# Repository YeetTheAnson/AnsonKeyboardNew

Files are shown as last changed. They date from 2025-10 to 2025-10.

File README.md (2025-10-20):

# Anson's Keyboard
This is a generic looking 80% TKL keyboard I made over the span of a month. In total, I've spent about 20-25 hours in total for PCB redesigns, writing the keyboard firmware and case redesigns.

## Features
- Individually backlit keys with software addressable RGB
- 0.91" OLED display
- USB and Bluetooth connectivity

### LED Control
The keyboard has three LED modes:
1. **Off Mode**: All LEDs are turned off
2. **RGB Mode**: LEDs display a rainbow effect
3. **Custom Color Mode**: All LEDs use a user-defined color

### LED Mode Controls
* **Toggle LED Mode**: `Ctrl + Alt + Pause/Break`
   * Cycles through Off → RGB → Custom Color
* **Adjust Brightness Up**: `Ctrl + Alt + Shift + Up Arrow`
* **Adjust Brightness Down**: `Ctrl + Alt + Shift + Down Arrow`

### Custom Color Configuration
1. **Enter Custom Color Mode**: `Ctrl + Alt + Page Up`
2. When in custom color mode:
   * The OLED will prompt for R, G, and B values sequentially
   * Use number keys (0-9) to enter a value between 0-255
   * Press `Backspace` to delete the last digit
   * Press `Enter` to confirm and move to the next color component
   * After setting all three RGB values, the keyboard returns to normal operation with your custom color

### Bluetooth Functionality
The keyboard can operate in either USB or Bluetooth mode:
* **Check Current Mode**: The OLED screen displays either "USB Mode" or "BT Mode"
* **Switch to Bluetooth Mode**: Hold the Pause/Break key during boot (pin IO36)
   * Note: After setup, the keyboard will remain in Bluetooth mode until changed

### OLED Display
The OLED display shows:
1. "AnsonKeyboard"
2. Connection mode (USB or Bluetooth)
3. Current WPM (words per minute) typing speed
4. Current LED mode

When in custom color configuration mode, the display shows prompts for entering RGB values.

### Performance Monitoring
The keyboard automatically calculates your typing speed (WPM) and displays it on the OLED screen. This is calculated based on:
* Number of keypresses
* Time elapsed since last keypress
* Standard conversion (5 characters = 1 word)

### Special Key Combinations
| Function | Key Combination |
|---|---|
| Toggle LED Mode | Ctrl + Alt + Pause/Break |
| Enter Custom Color Mode | Ctrl + Alt + Page Up |
| Increase LED Brightness | Ctrl + Alt + Shift + Up Arrow |
| Decrease LED Brightness | Ctrl + Alt + Shift + Down Arrow |
| Enter Bluetooth Mode | Hold Pause/Break during boot |

## Design Process
I started with a simple idea which was a flat minimalistic TKL keyboard (inspired by the Apple keyboard). The goal was to keep it clean and 
modern, and remove unnecessary designs. However, as I thought more about ergonomics, I quickly realized that a completely flat keyboard wouldn't be comfortable at all
to use during typing.

My initial PCB design had borders that were too thick, which also made the case borders too thick, it was quite bulky and uglier than what I wanted

I originally planned to use the Orpheus Pico as the microcontroller. However, due to the large footprint (making the case even bulkier) and the lack of wireless connectivity, I scrapped that idea
and moved on to a new design. At this point, I also decided to make a triangle wedge to set the keyboard at 6 degrees for a better typing experience.

I wanted an integrated USB C port directly on the PCB, but when I redesigned the case and PCB to fit it, I realized that it would be close to impossible for someone with my skill level to hand solder the USB C port and it
would have stuck up at an angle anyway (this stresses the cable)

For the final design, I came up a solution. Instead of mounting the USB C port directly onto the PCB, I would purchase a USB C breakout board instead and connect it via cables to the PCB. 

(This is when the routing hell begins as I reroute the entire thing at least 3 times)
The first time was my extremely inefficient matrix which was a 8x11 matrix. The traces were extremely messy and I've counted about 1.1k traces and 500 vias in total. (I'm so glad I don't have to see it again). I've then updated it to a 7x14 matrix which made routing much easier.
The second time was when I had to move all LEDs down by 2mm since they didn't align with the cutout in the switches.
Not even an hour after posting about my rerouting, someone from Slack recommmended that I wire my LEDs from top to bottom instead of side to side as to reduce via usage. This is the current version of the PCB and I'm quite happy with it

# Pictures
## Schematic
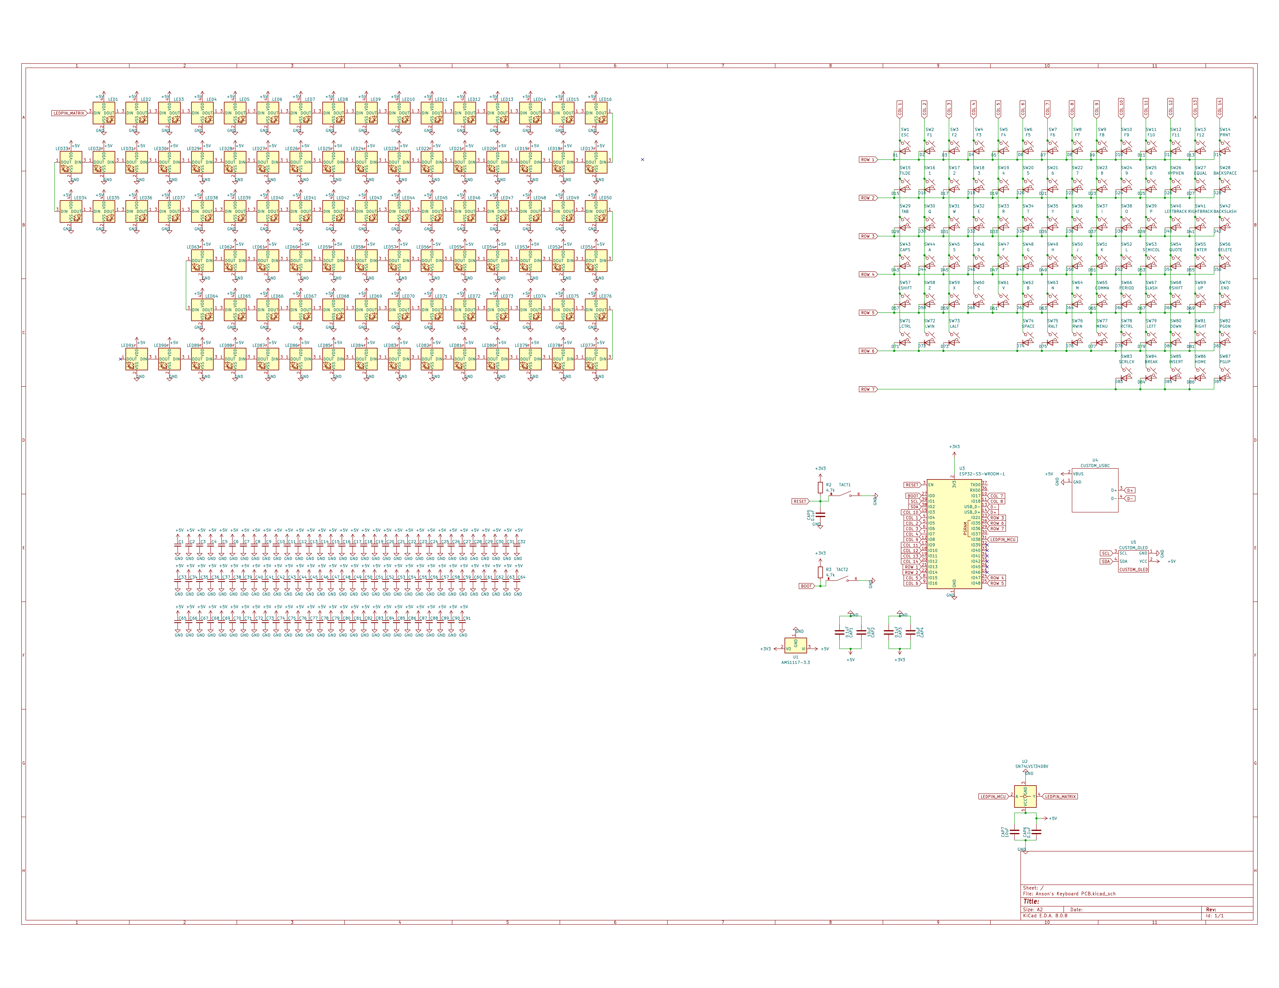
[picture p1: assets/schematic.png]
schematic


## PCB
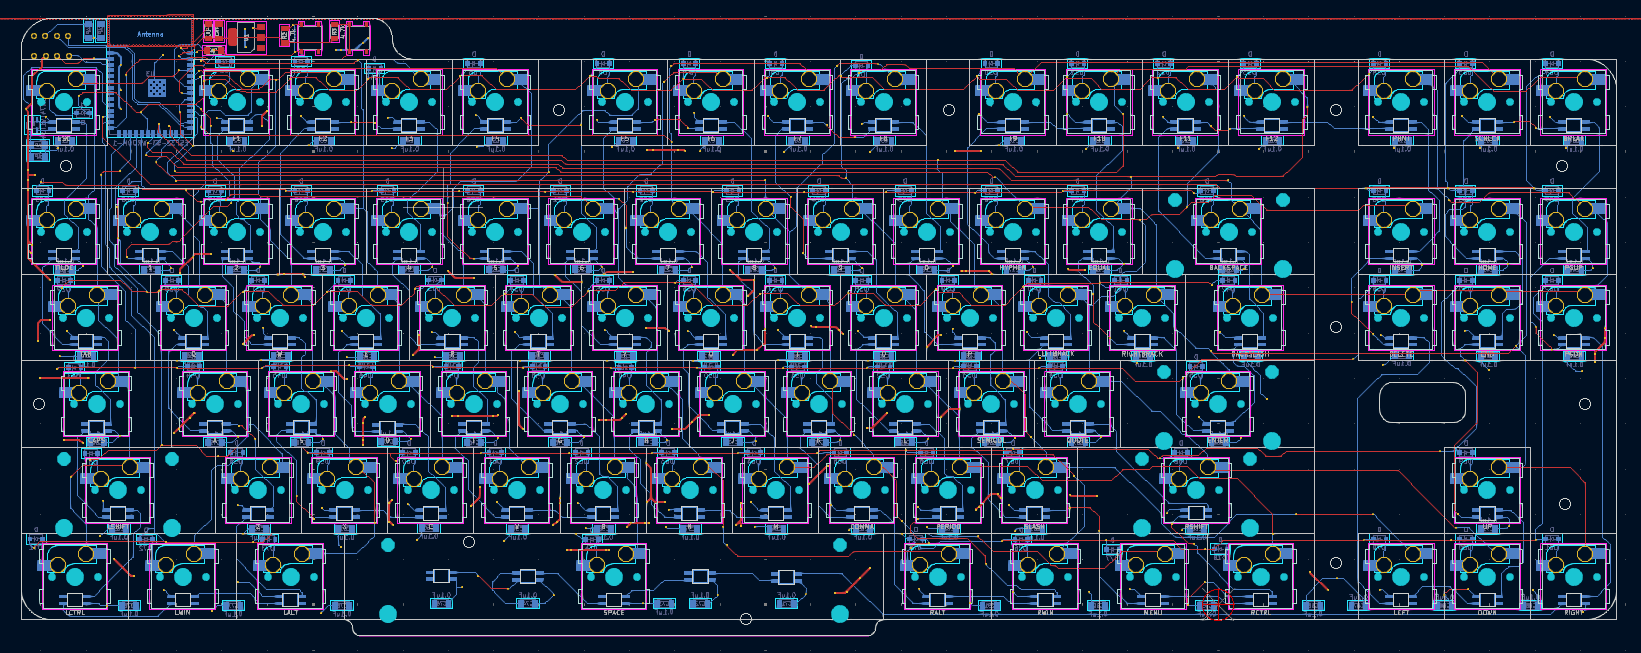
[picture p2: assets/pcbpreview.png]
pcbpreview

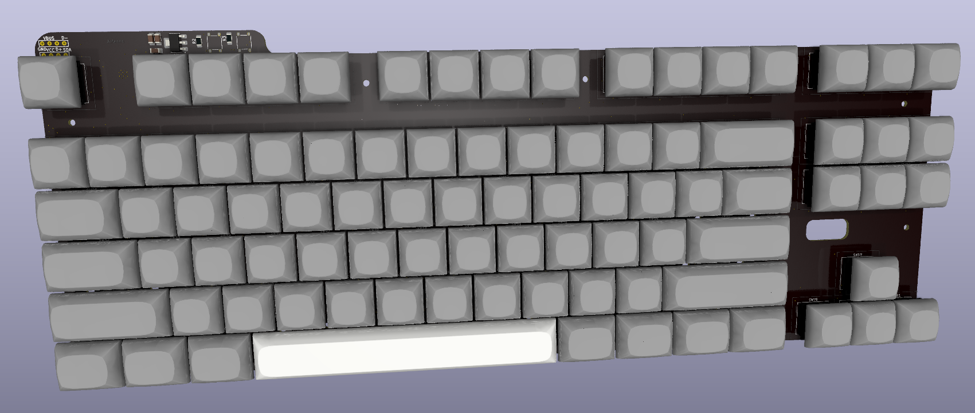
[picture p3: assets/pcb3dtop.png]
pcb3dtop

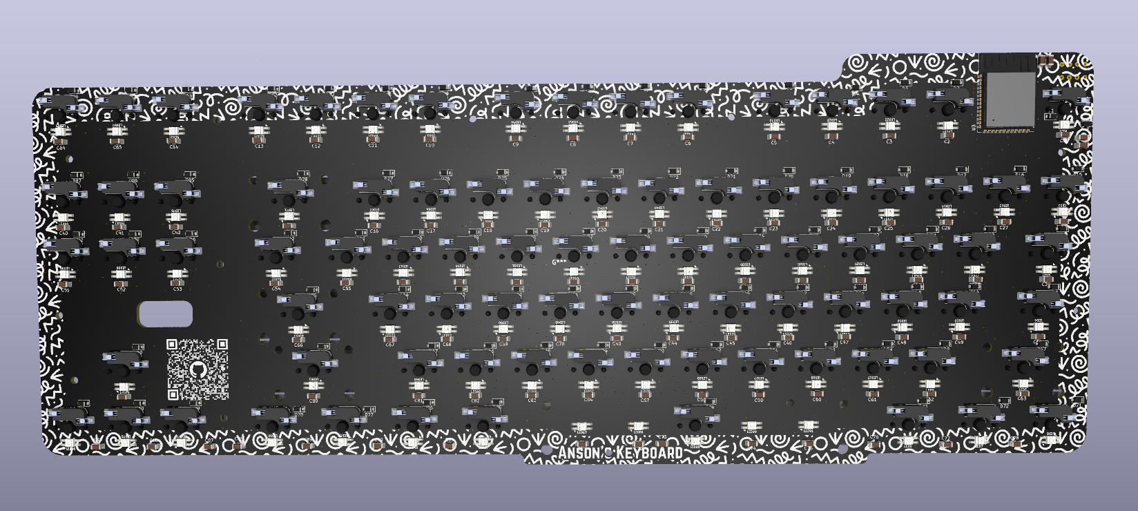
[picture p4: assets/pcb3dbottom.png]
pcb3dbottom


## Renders
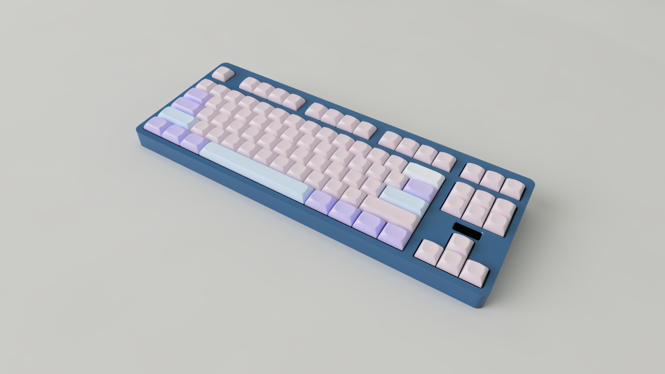
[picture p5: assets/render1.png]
render1

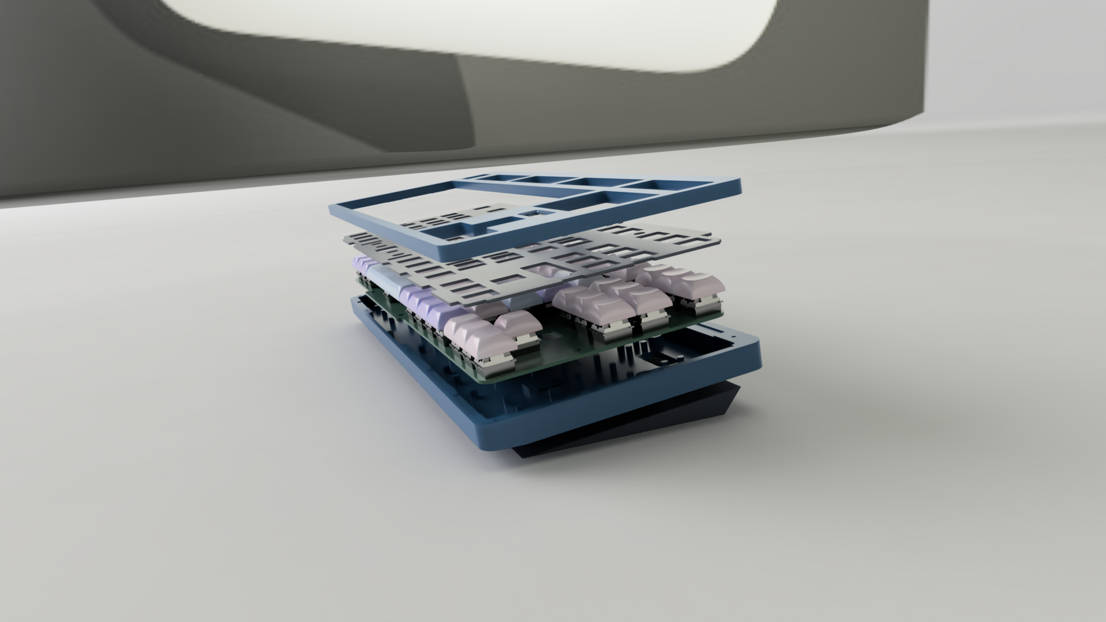
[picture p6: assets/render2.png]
render2

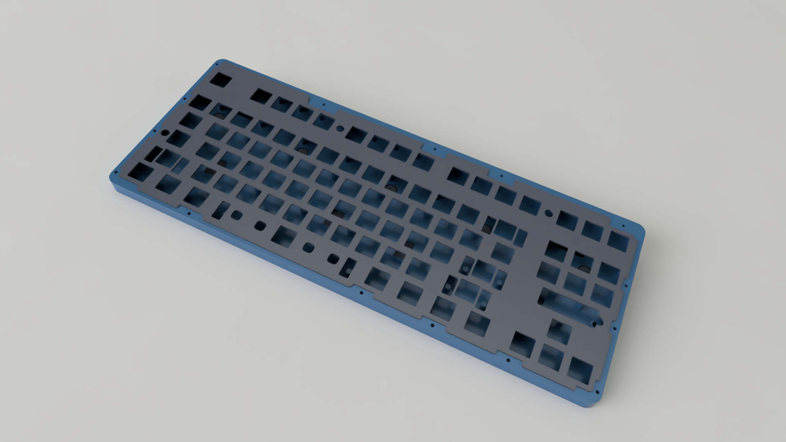
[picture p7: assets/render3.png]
render3

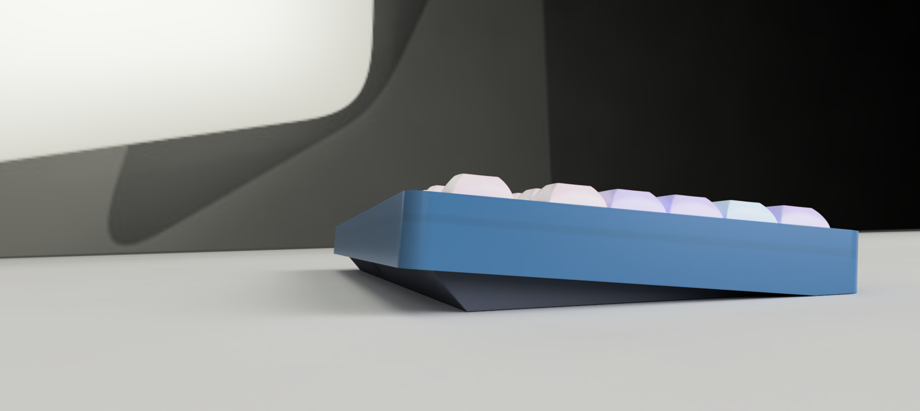
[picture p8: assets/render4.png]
render4

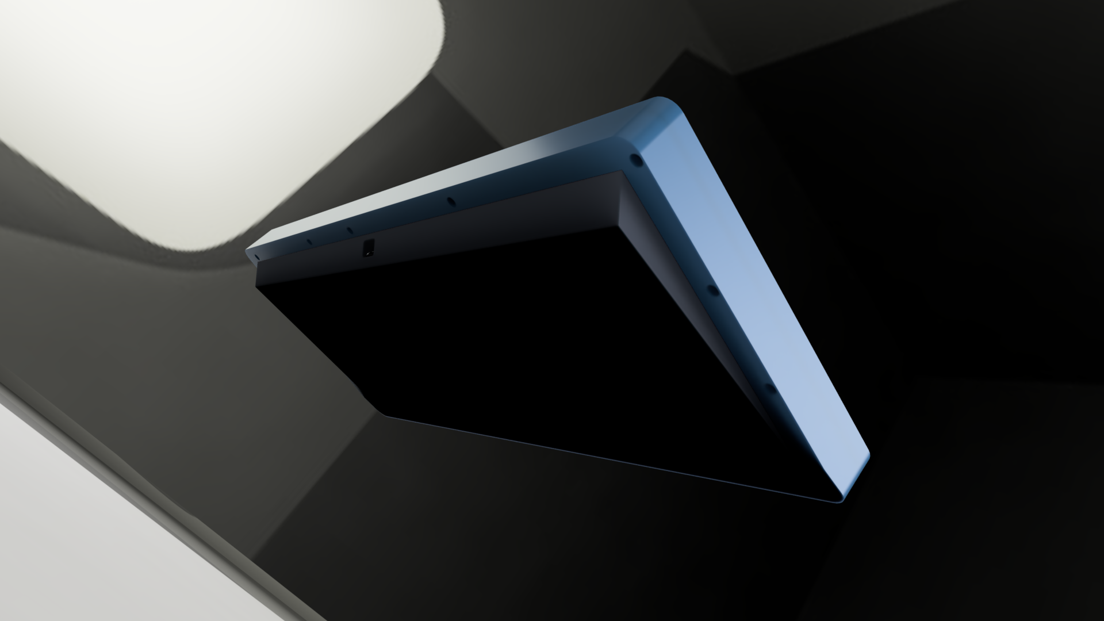
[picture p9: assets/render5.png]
render5


## Case Stand (CaseStand.step)
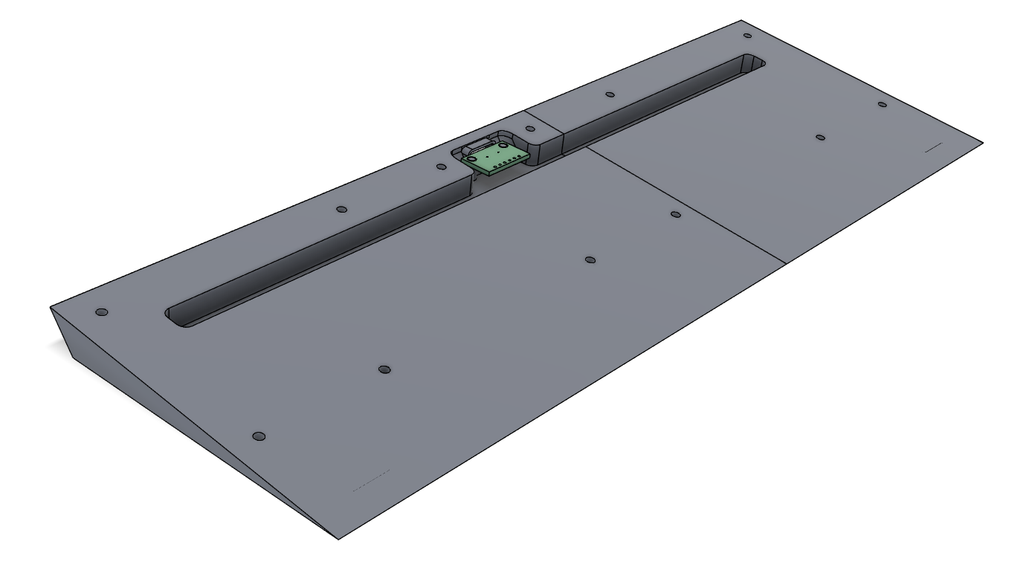
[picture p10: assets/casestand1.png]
casestand1

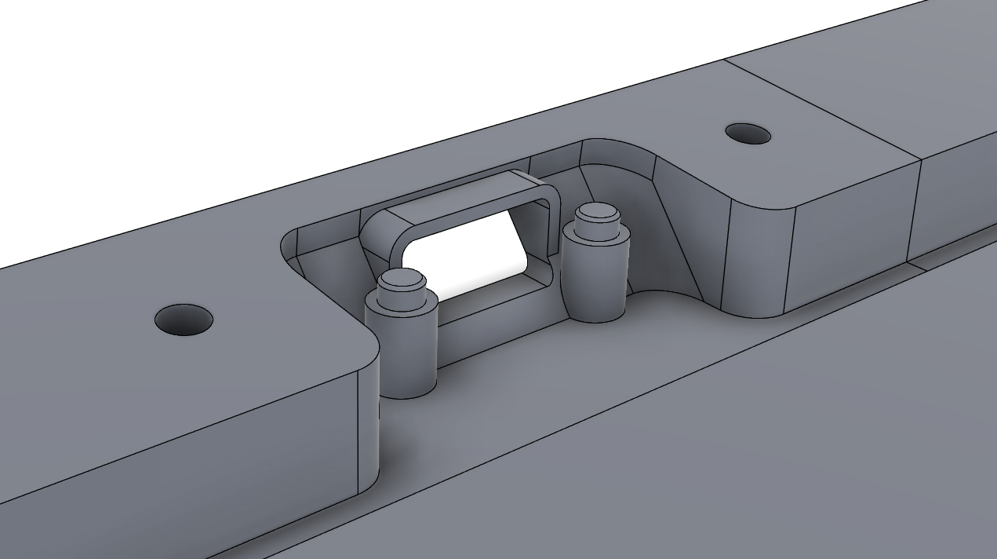
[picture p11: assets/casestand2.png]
casestand2

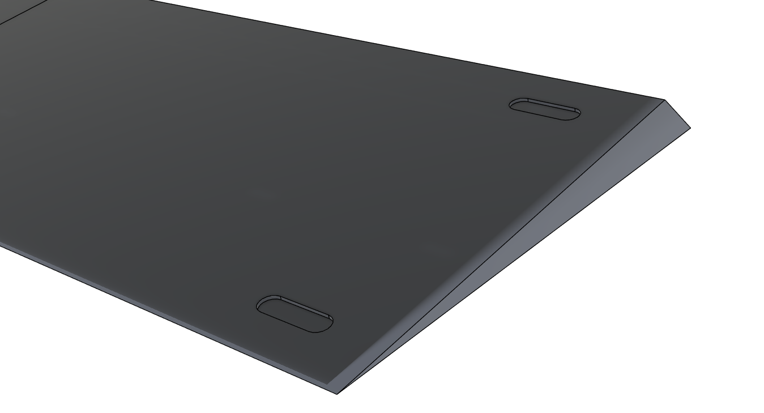
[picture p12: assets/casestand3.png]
casestand3


## Lower Case (LowerCase.step)
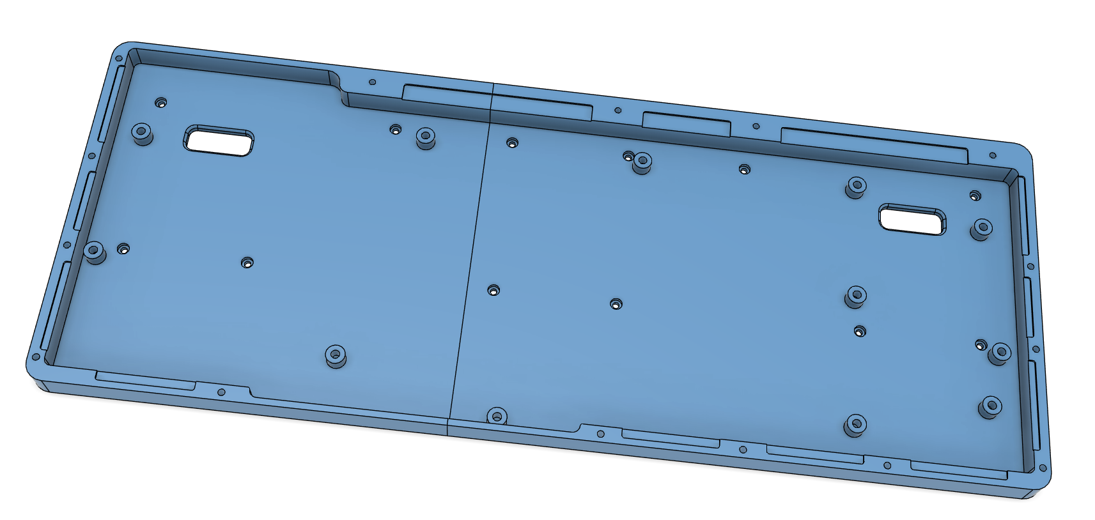
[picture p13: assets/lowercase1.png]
lowercase1

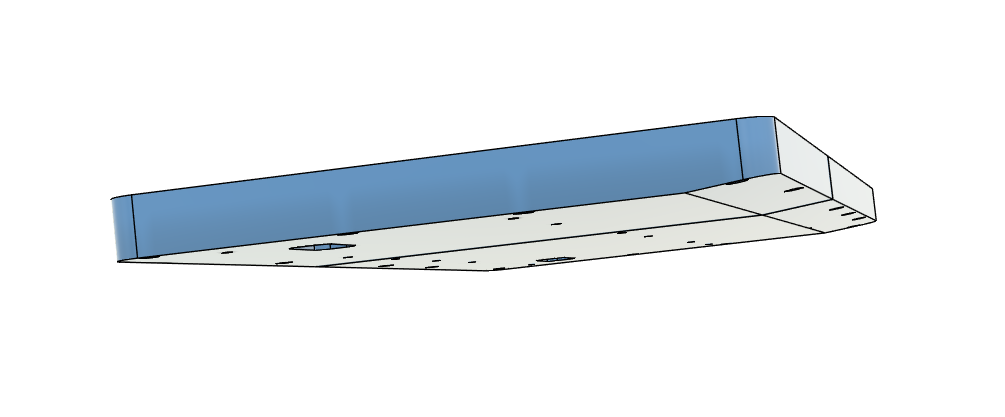
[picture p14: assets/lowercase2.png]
lowercase2


## Plate (Plate.step)
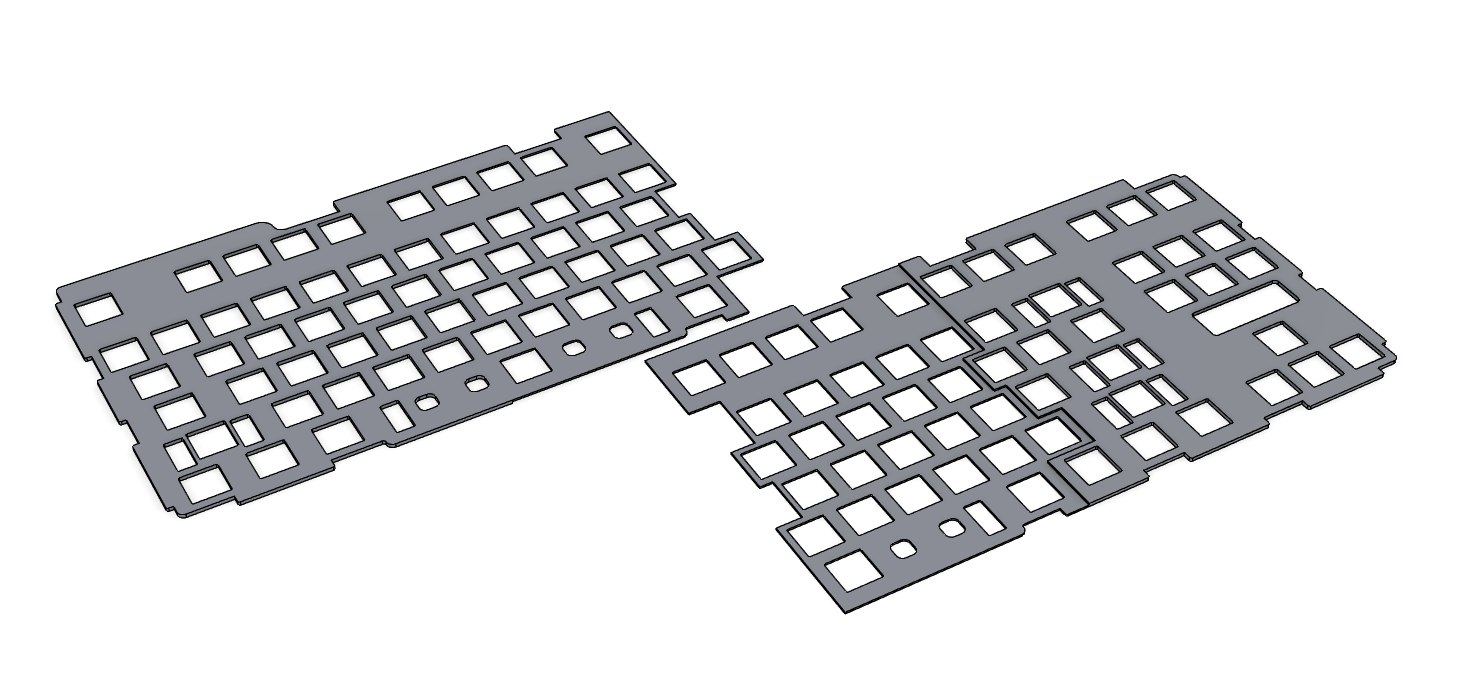
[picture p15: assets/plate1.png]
plate1


## Top Case (TopCase.step)
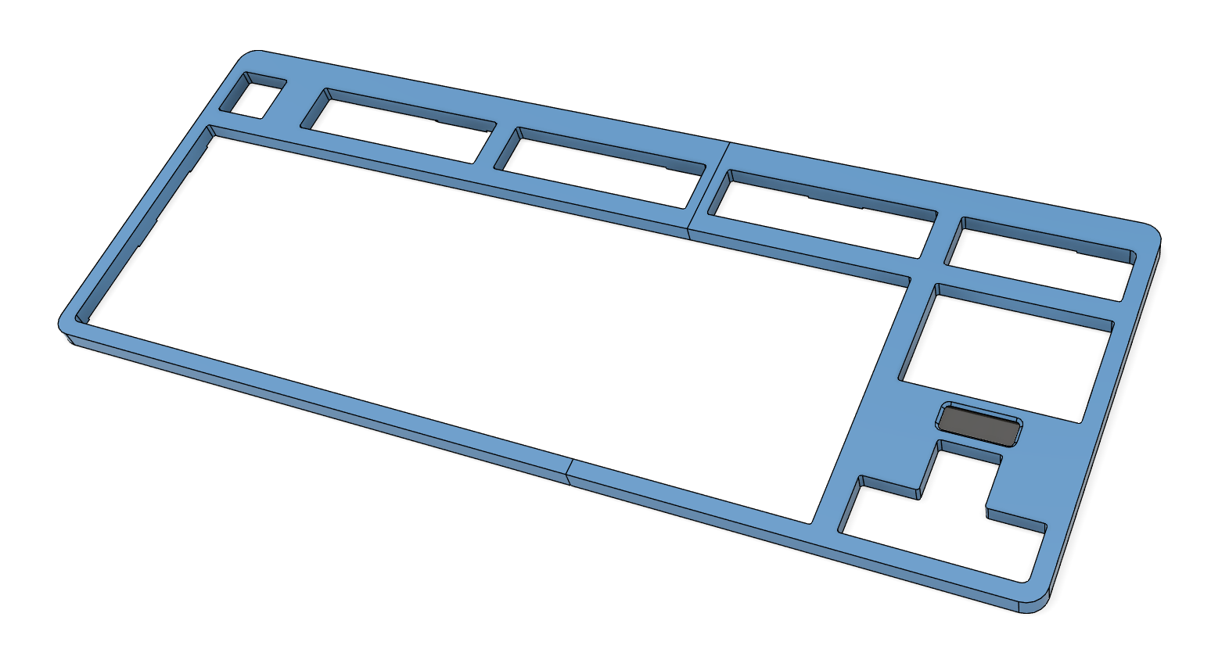
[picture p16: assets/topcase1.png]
topcase1

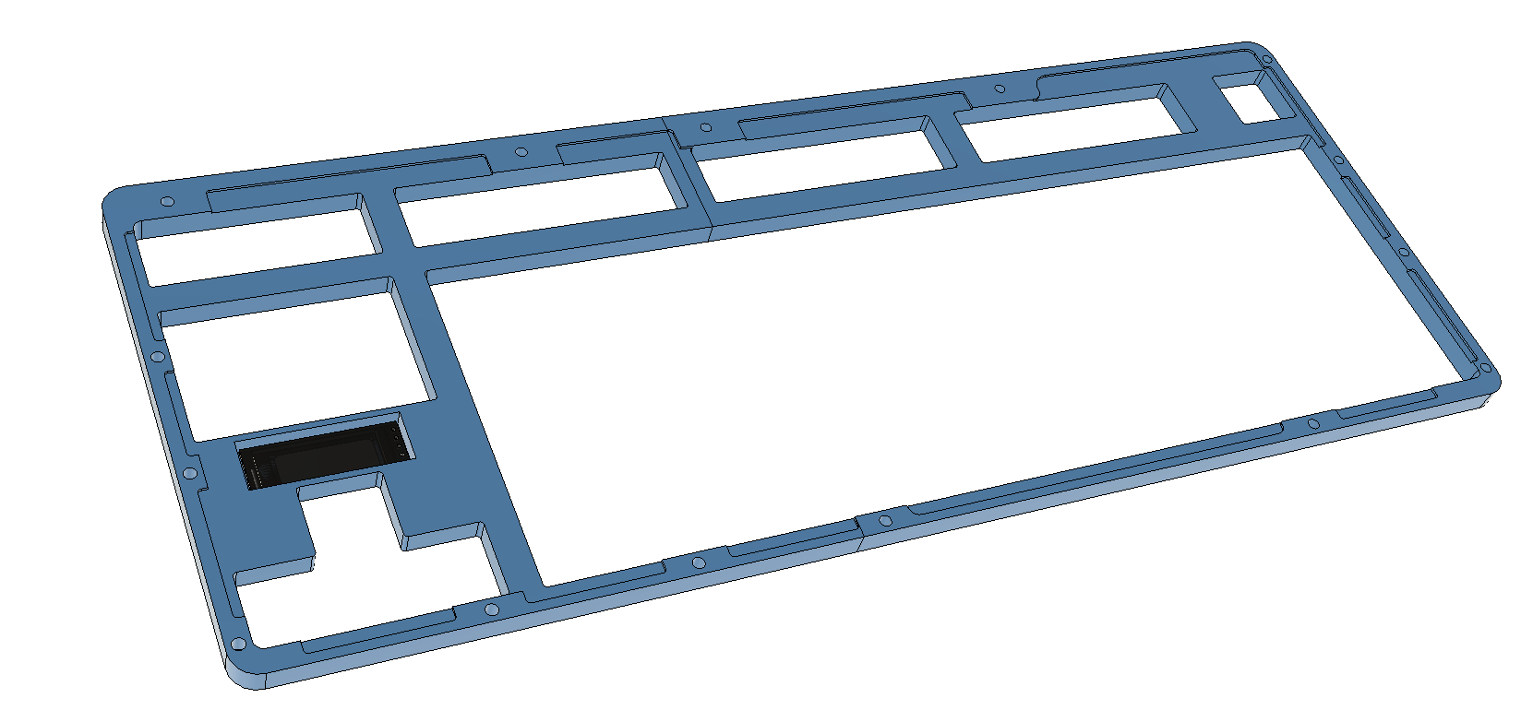
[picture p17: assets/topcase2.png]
topcase2


# Bill Of Material

## Electronics (LCSC)

### Passive Components

| QTY  | Name | Part Number | LCSC Part Number | Price |
|---|---|---|---|---|
| 100x | 4.7kΩ Resistor | 1206W4F4701T5E | [C17936](https://www.lcsc.com/product-detail/Chip-Resistor-Surface-Mount_UNI-ROYAL-Uniroyal-Elec-1206W4F4701T5E_C17936.html) | $0.32 |
| 100x | 5.1kΩ Resistor | 1206W4F5101T5E | [C26033](https://www.lcsc.com/product-detail/Chip-Resistor-Surface-Mount_UNI-ROYAL-Uniroyal-Elec-1206W4F5101T5E_C26033.html) | $0.32 |
| 20x  | Tact Switch | TS-1187A-B-A-B | [C318884](https://www.lcsc.com/product-detail/Tactile-Switches_XKB-Connection-TS-1187A-B-A-B_C318884.html) | $0.38 |
| 5x | 3.3v Regulator | AMS1117-3.3 | [C6186](https://www.lcsc.com/product-detail/Voltage-Regulators-Linear-Low-Drop-Out-LDO-Regulators_Advanced-Monolithic-Systems-AMS1117-3-3_C6186.html) | $0.84 |
| 150x | 100nF Capacitor | CC1206KRX7R9BB104  | [C82601](https://www.lcsc.com/product-detail/Multilayer-Ceramic-Capacitors-MLCC-SMD-SMT_YAGEO-CC1206KRX7R9BB104_C82601.html) | $1.61 |
| 20x  | 10uF Capacitor | CL31B106KAHNNNE | [C14860](https://www.lcsc.com/product-detail/Multilayer-Ceramic-Capacitors-MLCC-SMD-SMT_Samsung-Electro-Mechanics-CL31B106KAHNNNE_C14860.html) | $0.54 |
| 200x | Diode | 1N4148WL | [C33962554](https://www.lcsc.com/product-detail/Diodes-General-Purpose_Slkor-SLKORMICRO-Elec-1N4148WL_C33962554.html) | $1.00 |

### Active Components

| QTY  | Name | Part Number | LCSC Part Number | Price |
|---|---|---|---|---|
| 150x | RGB LED | SK6812MINI-E | [C5149201](https://www.lcsc.com/product-detail/RGB-LEDs-Built-in-IC_OPSCO-Optoelectronics-SK6812MINI-E_C5149201.html) | $8.70 |
| 1x | ESP-32-S3 | ESP32-S3-WROOM-1-N16R2 | [C2913205](https://www.lcsc.com/product-detail/WiFi-Modules_Espressif-Systems-ESP32-S3-WROOM-1-N16R2_C2913205.html) | $5.04 |
| 10x  | Level Shifter | SN74LV1T34DBVR | [C100024](https://www.lcsc.com/product-detail/Buffers-Drivers-Receivers-Transceivers_Texas-Instruments-SN74LV1T34DBVR_C100024.html) | $0.59 |

**LCSC Shipping**: Singapore Post – $5.72  

## Electronics (Local Vendor. I will be paying for these)

| QTY  | Name | Local Price | Conversion Upcharge | Price |
|---|---|---|---|---|
| 5x | [USB C Breakout Board](https://shopee.com.my/product/145270449/29272008539) | RM8.13 | +$0.15 | $2.10 |
| 1x  | [0.91" OLED](https://shopee.com.my/product/145270449/4639327724) | RM10.62 | +$0.15 | $2.65 |
| 1x | SPX Express Shipping | RM5.20 | +$0.15 | $1.40 |

---

## Production  

| QTY  | Name | File Name | Production Method | Price  |
|---|---|---|---|---|
| 1x | Top Case  | TopCase.step  | FDM 3D Print | - |
| 1x | Plate | Plate.step | FDM 3D Print | - |
| 1x | Lower Case | LowerCase.step | FDM 3D Print | - |
| 1x | Case Stand | CaseStand.step | FDM 3D Print | - |
| 5x | PCB | gerbers.zip | JLCPCB | $22.20 |
| 1x | PCB Shipping | - | E-Post | $9.76 |

---

## Fasteners  

| QTY  | Name | Local Price | Conversion Upcharge | Price |
|---|---|---|---|---|
| 27x  | [M2 x 3.5 x 4 Heat Set Insert](https://shopee.com.my/-M2-M2.5-M3-Helical-Knurled-Embedded-Nut-Heat-Set-Threaded-Insert-3D-Printing-Injection-Molding-Laptop-Repair-Brass-i.327548229.21958741418) | RM9.45 | +$0.15 | $2.39 |
| 12x  | [M2 x 3.5 x 2 Heat Set Insert](https://shopee.com.my/-M2-M2.5-M3-Helical-Knurled-Embedded-Nut-Heat-Set-Threaded-Insert-3D-Printing-Injection-Molding-Laptop-Repair-Brass-i.327548229.21958741418) | RM4.20 | +$0.15 | $1.14 |
| 12x  | [M2 x 5mm Hex Screw](https://shopee.com.my/M2-M2.5-Hex-Socket-Button-Head-Cap-Screw-Allen-Key-Bolt-Skru-Stainless-Steel-304-i.327548229.14990997313) | RM4.56 | +$0.15 | $1.23 |
| 12x  | [M2 x 3mm Hex Screw](https://shopee.com.my/M2-M2.5-Hex-Socket-Button-Head-Cap-Screw-Allen-Key-Bolt-Skru-Stainless-Steel-304-i.327548229.14990997313) | RM4.08 | +$0.15 | $1.12 |
| 15x  | [M2 x 12mm Hex Screw](https://shopee.com.my/M2-M2.5-Hex-Socket-Button-Head-Cap-Screw-Allen-Key-Bolt-Skru-Stainless-Steel-304-i.327548229.14990997313) | RM6.90 | +$0.15 | $1.78 |
| 1x | SPX Express Shipping | RM10.60 | +$0.15 | $2.66 |

---

## Mechanical  

| QTY  | Name | Local Price | Conversion Upcharge | Price |
|---|---|---|---|---|
| 1x | [XDA Keycap Set](https://shopee.com.my/MKB-Cinnamoroll-Sanrio-PBT-XDA-Profile-Keycap-Set-for-Mechanical-Keyboard-i.72068395.18262626381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) | RM91.20 | +$2.50 | $24.14 |
| 1x | [TX Almost Perfect Stabilizers](https://shopee.com.my/product/72068395/18489170375) | RM74.80 | +$2.50 | $20.25 |
| 91x  | [Gateron Smoothie Switches](https://shopee.com.my/product/72068395/14635071158) | RM136.50 | +$4.00 | $35.42 |
| 1x | SPX Express Shipping | RM17.00 | +$0.40  | $4.31 |

---

## Total Costs  

- **LCSC Total**: $25.06  
- **Electronics (Local) Total**: $6.15
- **JLCPCB Total**: $31.96  
- **Fasteners Total**: $10.32  
- **Mechanical Total**: $84.12  

## **Grand Total: $157.61**

**Note:** Conversion upcharge is just a buffer for conversion rate fluctuations. Any unused funds will be returned.

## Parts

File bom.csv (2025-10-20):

Category | Item Name | Part Number / File Name | Link | Vendor | Quantity | Total Price (USD)
Electronics (LCSC) - Passive | 4.7kΩ Resistor | 1206W4F4701T5E | https://www.lcsc.com/product-detail/Chip-Resistor-Surface-Mount_UNI-ROYAL-Uniroyal-Elec-1206W4F4701T5E_C17936.html | LCSC | 100x | 0.32
Electronics (LCSC) - Passive | 5.1kΩ Resistor | 1206W4F5101T5E | https://www.lcsc.com/product-detail/Chip-Resistor-Surface-Mount_UNI-ROYAL-Uniroyal-Elec-1206W4F5101T5E_C26033.html | LCSC | 100x | 0.32
Electronics (LCSC) - Passive | Tact Switch | TS-1187A-B-A-B | https://www.lcsc.com/product-detail/Tactile-Switches_XKB-Connection-TS-1187A-B-A-B_C318884.html | LCSC | 20x | 0.38
Electronics (LCSC) - Passive | 3.3v Regulator | AMS1117-3.3 | https://www.lcsc.com/product-detail/Voltage-Regulators-Linear-Low-Drop-Out-LDO-Regulators_Advanced-Monolithic-Systems-AMS1117-3-3_C6186.html | LCSC | 5x | 0.84
Electronics (LCSC) - Passive | 100nF Capacitor | CC1206KRX7R9BB104 | https://www.lcsc.com/product-detail/Multilayer-Ceramic-Capacitors-MLCC-SMD-SMT_YAGEO-CC1206KRX7R9BB104_C82601.html | LCSC | 150x | 1.61
Electronics (LCSC) - Passive | 10uF Capacitor | CL31B106KAHNNNE | https://www.lcsc.com/product-detail/Multilayer-Ceramic-Capacitors-MLCC-SMD-SMT_Samsung-Electro-Mechanics-CL31B106KAHNNNE_C14860.html | LCSC | 20x | 0.54
Electronics (LCSC) - Passive | Diode | 1N4148WL | https://www.lcsc.com/product-detail/Diodes-General-Purpose_Slkor-SLKORMICRO-Elec-1N4148WL_C33962554.html | LCSC | 200x | 1.00
Electronics (LCSC) - Active | RGB LED | SK6812MINI-E | https://www.lcsc.com/product-detail/RGB-LEDs-Built-in-IC_OPSCO-Optoelectronics-SK6812MINI-E_C5149201.html | LCSC | 150x | 8.70
Electronics (LCSC) - Active | ESP-32-S3 | ESP32-S3-WROOM-1-N16R2 | https://www.lcsc.com/product-detail/WiFi-Modules_Espressif-Systems-ESP32-S3-WROOM-1-N16R2_C2913205.html | LCSC | 1x | 5.04
Electronics (LCSC) - Active | Level Shifter | SN74LV1T34DBVR | https://www.lcsc.com/product-detail/Buffers-Drivers-Receivers-Transceivers_Texas-Instruments-SN74LV1T34DBVR_C100024.html | LCSC | 10x | 0.59
Electronics (Local) | USB C Breakout Board |  | https://shopee.com.my/product/145270449/29272008539 | Local Vendor (Shopee) | 5x | 2.10
Electronics (Local) | 0.91" OLED |  | https://shopee.com.my/product/145270449/4639327724 | Local Vendor (Shopee) | 1x | 2.65
Production | Top Case | TopCase.step |  | FDM 3D Print | 1x | 0.00
Production | Plate | Plate.step |  | FDM 3D Print | 1x | 0.00
Production | Lower Case | LowerCase.step |  | FDM 3D Print | 1x | 0.00
Production | Case Stand | CaseStand.step |  | FDM 3D Print | 1x | 0.00
Production | PCB | gerbers.zip |  | JLCPCB | 5x | 22.20
Fasteners | M2 x 3.5 x 4 Heat Set Insert |  | https://shopee.com.my/-M2-M2.5-M3-Helical-Knurled-Embedded-Nut-Heat-Set-Threaded-Insert-3D-Printing-Injection-Molding-Laptop-Repair-Brass-i.327548229.21958741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 | Local Vendor (Shopee) | 27x | 2.39
Fasteners | M2 x 3.5 x 2 Heat Set Insert |  | https://shopee.com.my/-M2-M2.5-M3-Helical-Knurled-Embedded-Nut-Heat-Set-Threaded-Insert-3D-Printing-Injection-Molding-Laptop-Repair-Brass-i.327548229.21958741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 | Local Vendor (Shopee) | 12x | 1.14
Fasteners | M2 x 5mm Hex Screw |  | https://shopee.com.my/M2-M2.5-Hex-Socket-Button-Head-Cap-Screw-Allen-Key-Bolt-Skru-Stainless-Steel-304-i.327548229.14990997313 | Local Vendor (Shopee) | 12x | 1.23
Fasteners | M2 x 3mm Hex Screw |  | https://shopee.com.my/M2-M2.5-Hex-Socket-Button-Head-Cap-Screw-Allen-Key-Bolt-Skru-Stainless-Steel-304-i.327548229.14990997313 | Local Vendor (Shopee) | 12x | 1.12
Fasteners | M2 x 12mm Hex Screw |  | https://shopee.com.my/M2-M2.5-Hex-Socket-Button-Head-Cap-Screw-Allen-Key-Bolt-Skru-Stainless-Steel-304-i.327548229.14990997313 | Local Vendor (Shopee) | 15x | 1.78
Mechanical | XDA Keycap Set |  | https://shopee.com.my/MKB-Cinnamoroll-Sanrio-PBT-XDA-Profile-Keycap-Set-for-Mechanical-Keyboard-i.72068395.18262626381 | Local Vendor (Shopee) | 1x | 24.14
Mechanical | TX Almost Perfect Stabilizers |  | https://shopee.com.my/product/72068395/18489170375 | Local Vendor (Shopee) | 1x | 20.25
Mechanical | Gateron Smoothie Switches |  | https://shopee.com.my/product/72068395/14635071158 | Local Vendor (Shopee) | 91x | 35.42
Shipping | LCSC Shipping | Singapore Post |  | LCSC | 1 | 5.72
Shipping | Local Electronics Shipping | SPX Express |  | Local Vendor (Shopee) | 1 | 1.40
Shipping | PCB Shipping | E-Post |  | JLCPCB | 1 | 9.76
Shipping | Fasteners Shipping | SPX Express |  | Local Vendor (Shopee) | 1 | 2.66
Shipping | Mechanical Components Shipping | SPX Express |  | Local Vendor (Shopee) | 1 | 4.31
 |  |  |  |  | Grand Total: | 157.61

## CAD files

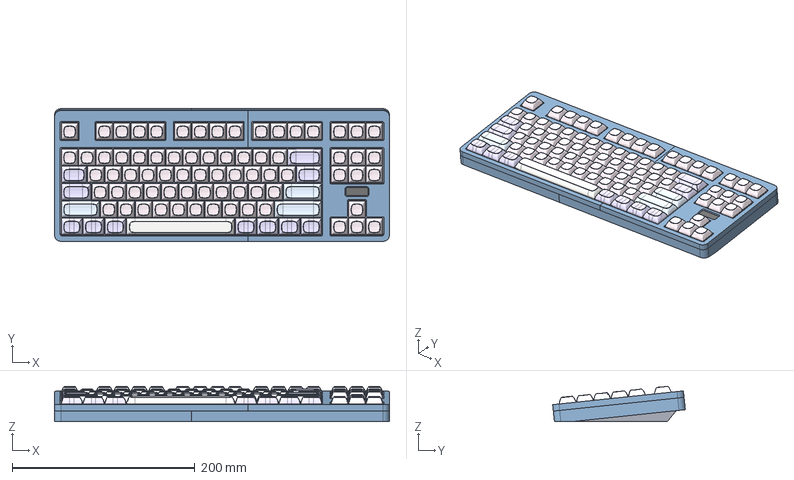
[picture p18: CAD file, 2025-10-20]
CAD/Assembled Keyboard.step
366.5 x 145.2 x 38.7 mm
[MAIN] Lower Case
R_0603_1608Metric_2 x 2
CQ-USB-C16PSMT01_1
_autosave-usbcbreakout_PCB
[MAIN] Plate
128x32-OLED
PG151101S11 x 87
cherry mx v28_1 x 81
DSA V4 1x1 v4 x 72
R_1206_3216Metric_2 x 2
DSA V4 1x1.5 v3 v1 v4 x 2
DSA V4 1x1.25 v3 v4 x 7
cherry mx v28 x 6
DSA V4 1x2.75 v1
DSA V4 1x1.75 v4
SOT_223
DSA V4 1x2.25 v3 x 2
C_1206_3216Metric_98 x 98
DSA V4 1x2 v4
DSA Spacebar 6.25u v2
SK6812MINI-E v4 x 91
D_SOD_123F x 87
ESP32-S3-WROOM-1_1
SOT_23_5

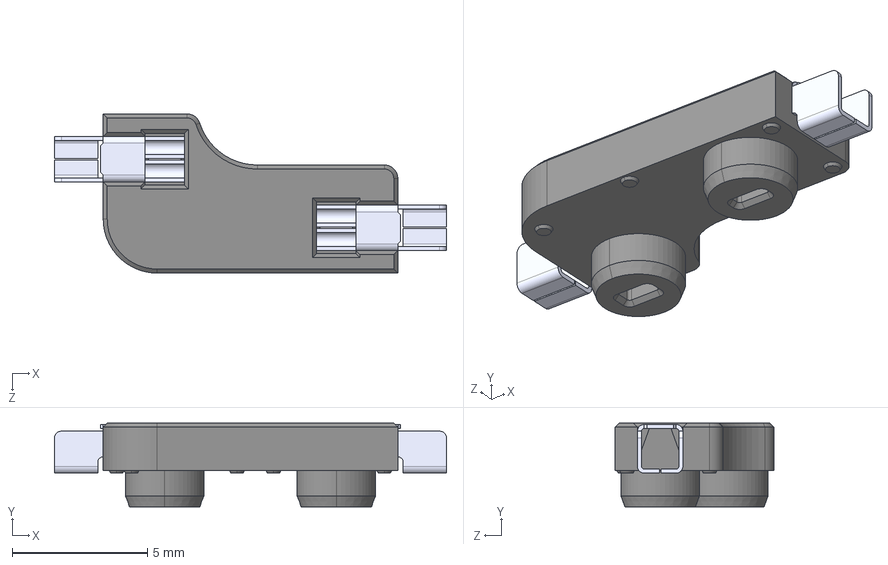
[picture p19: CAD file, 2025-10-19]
PCB/3d/kailhSocket.STEP
14.5 x 3.10 x 5.89 mm

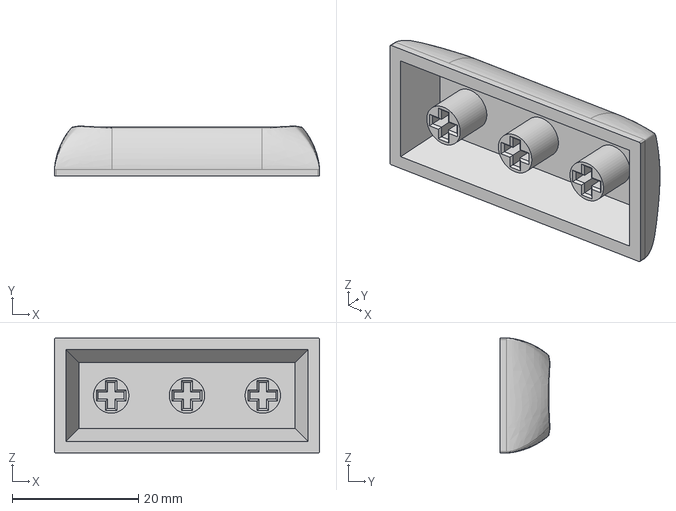
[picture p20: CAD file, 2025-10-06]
PCB/3d/keycap/DSA_2.25u.step
42.0 x 7.91 x 18.2 mm

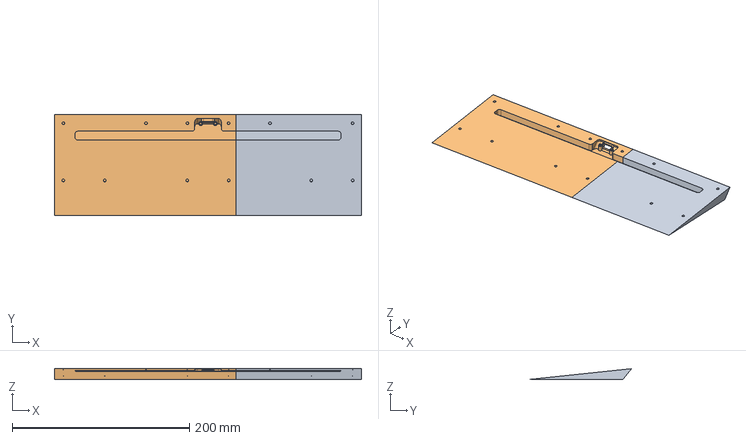
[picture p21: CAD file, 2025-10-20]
production/CaseStand.step
346.4 x 114.3 x 12.0 mm

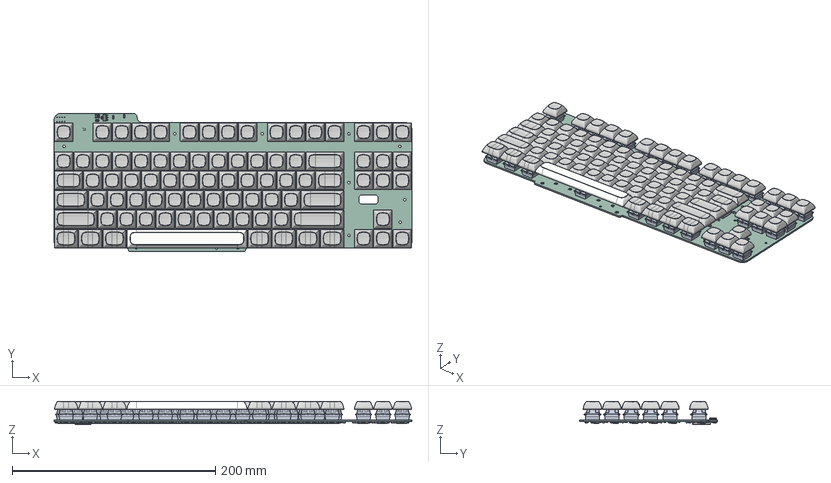
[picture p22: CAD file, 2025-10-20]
CAD/Anson's Keyboard PCB.step
352.5 x 136.4 x 22.8 mm
PG151101S11 x 87
cherry mx v28 x 87
DSA V4 1x1 v4 x 72
R_1206_3216Metric x 2
DSA V4 1x1.5 v3 v1 v4 x 2
DSA V4 1x1.25 v3 v4 x 7
DSA V4 1x2.75 v1
DSA V4 1x1.75 v4
SOT_223
DSA V4 1x2.25 v3 x 2
C_1206_3216Metric x 98
DSA V4 1x2 v4
DSA Spacebar 6.25u v2
SK6812MINI-E v4 x 91
D_SOD_123F x 87
ESP32-S3-WROOM-1
SOT_23_5
Anson's Keyboard PCB_PCB

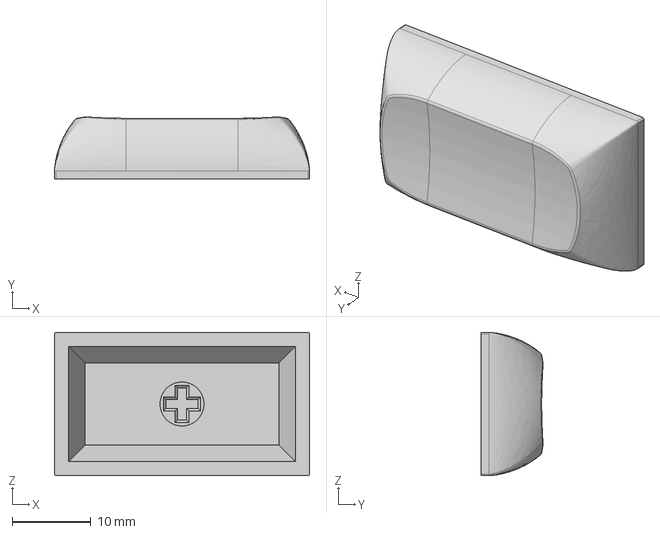
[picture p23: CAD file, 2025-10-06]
PCB/3d/keycap/DSA_1.75u.step
32.5 x 7.91 x 18.2 mm

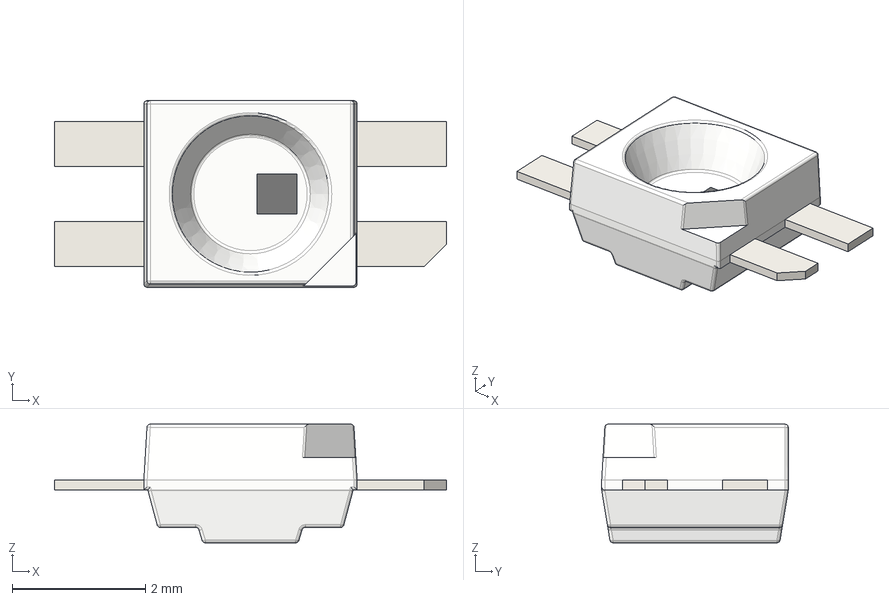
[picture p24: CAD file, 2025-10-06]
PCB/3d/LED_SK6812MINI-E.step
5.88 x 2.80 x 1.78 mm

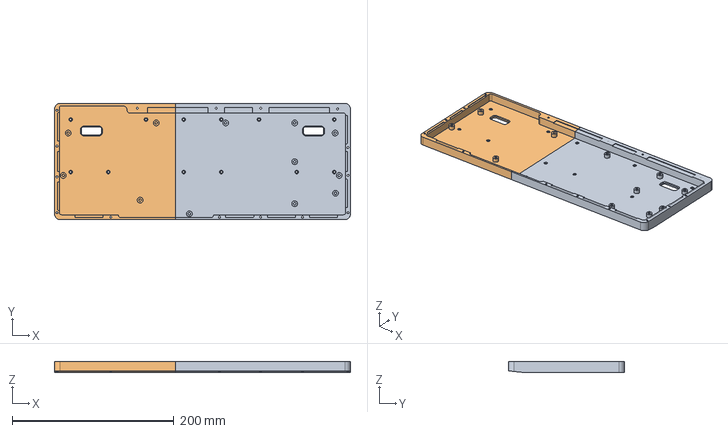
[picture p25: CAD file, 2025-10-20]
production/LowerCase.step
366.4 x 143.8 x 13.6 mm

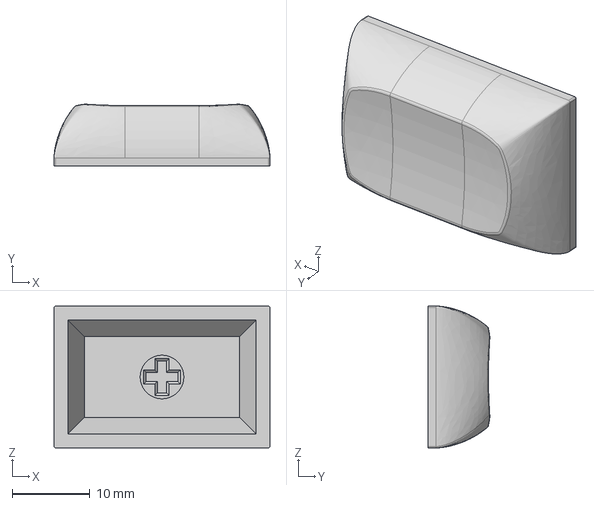
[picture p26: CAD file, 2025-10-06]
PCB/3d/keycap/DSA_1.5u.step
27.7 x 7.91 x 18.2 mm

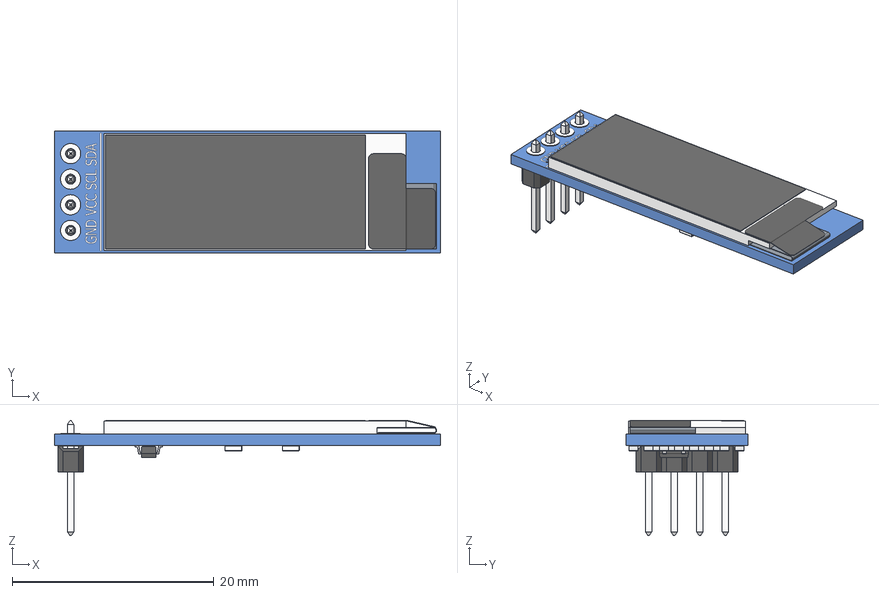
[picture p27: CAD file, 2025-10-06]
PCB/3d/OLED_0.91_128x32.stp
38.3 x 12.1 x 11.5 mm
OLED_0.91_128x32
Pin Header 4 x 1 TH 2.54mm Pitch
RESC-0603 x 13
2SD0601A

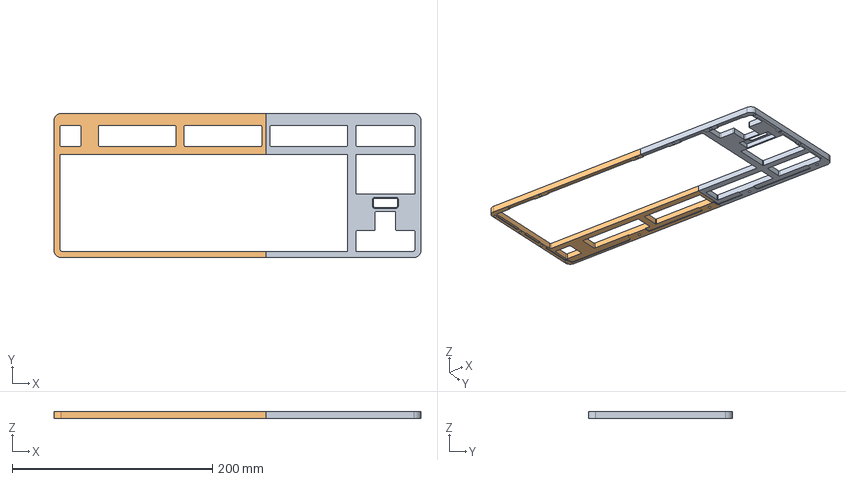
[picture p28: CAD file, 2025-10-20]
production/TopCase.step
366.4 x 143.8 x 7.08 mm

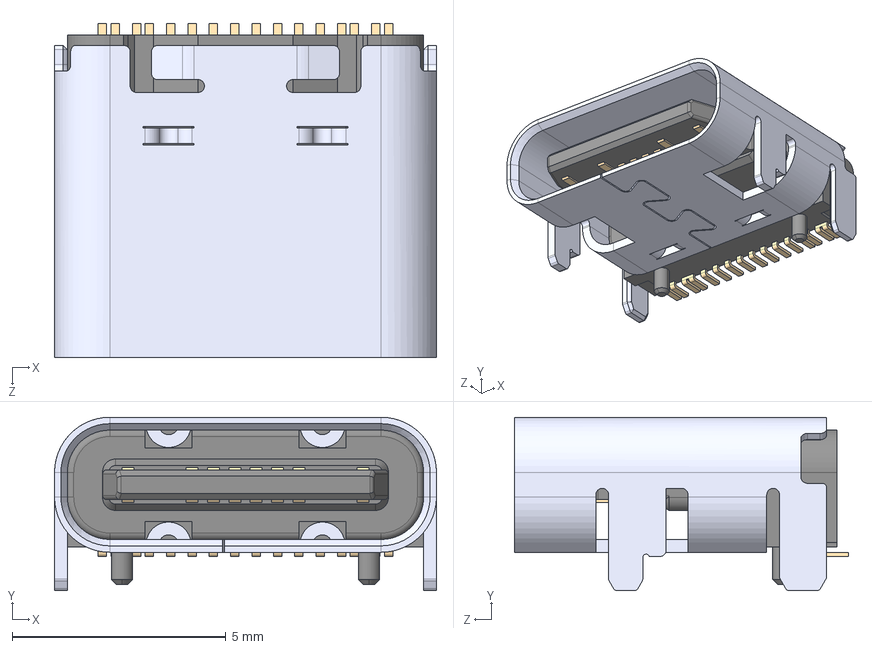
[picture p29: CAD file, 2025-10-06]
PCB/3d/CQ-USB-C16PSMT01.step
8.94 x 4.06 x 7.81 mm

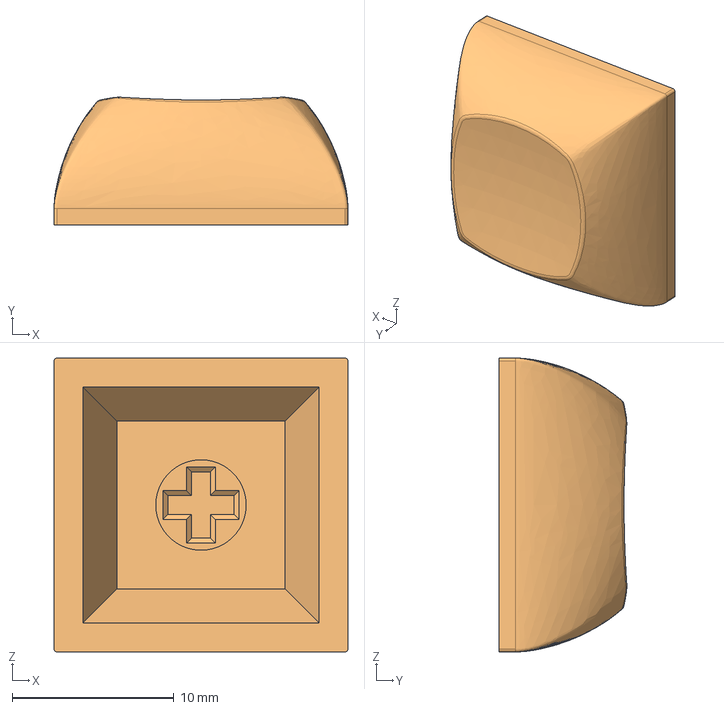
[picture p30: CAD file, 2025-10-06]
PCB/3d/keycap/DSA_1u.step
18.2 x 7.91 x 18.2 mm

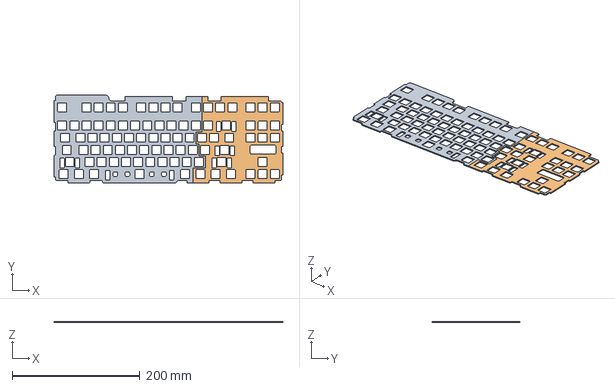
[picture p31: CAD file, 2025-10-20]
production/Plate.step
358.9 x 137.9 x 1.50 mm

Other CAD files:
PCB/3d/keycap/DSA_6.25u.step
PCB/3d/RASPBERRY_PI_PICO.step
PCB/3d/keycap/DSA_2u.step
PCB/3d/switch.step
PCB/3d/TS-1187A-B-A-B.step
PCB/3d/keycap/DSA_1.25u.step
PCB/3d/keycap/DSA_2.75u.step
PCB/3d/stabilizer.STEP

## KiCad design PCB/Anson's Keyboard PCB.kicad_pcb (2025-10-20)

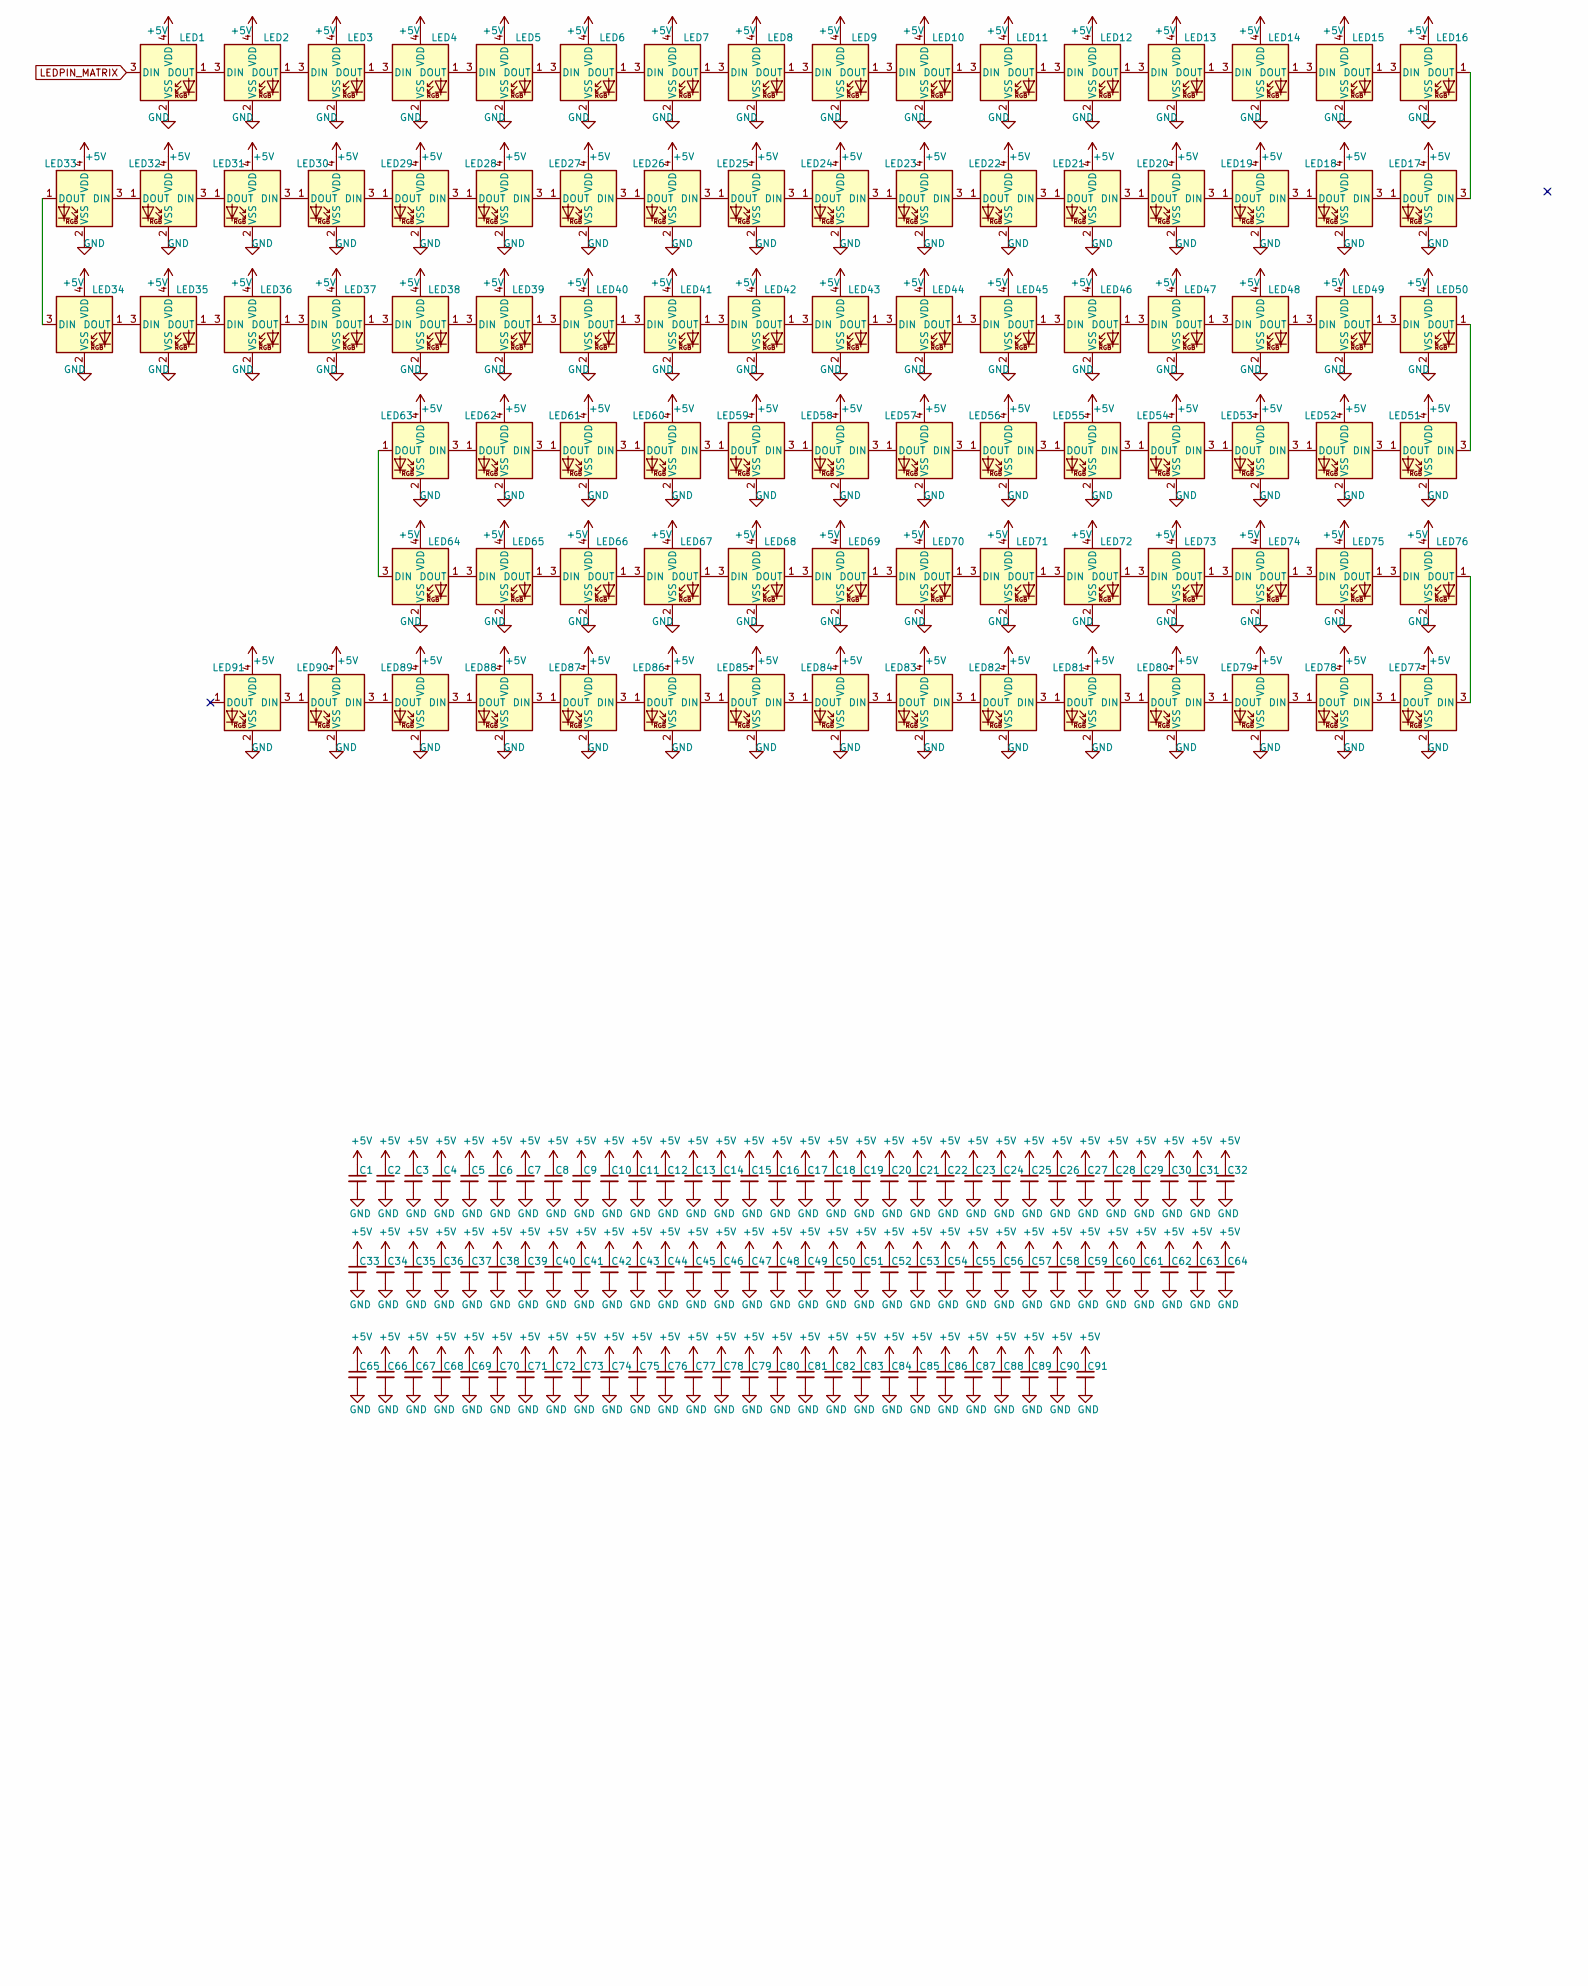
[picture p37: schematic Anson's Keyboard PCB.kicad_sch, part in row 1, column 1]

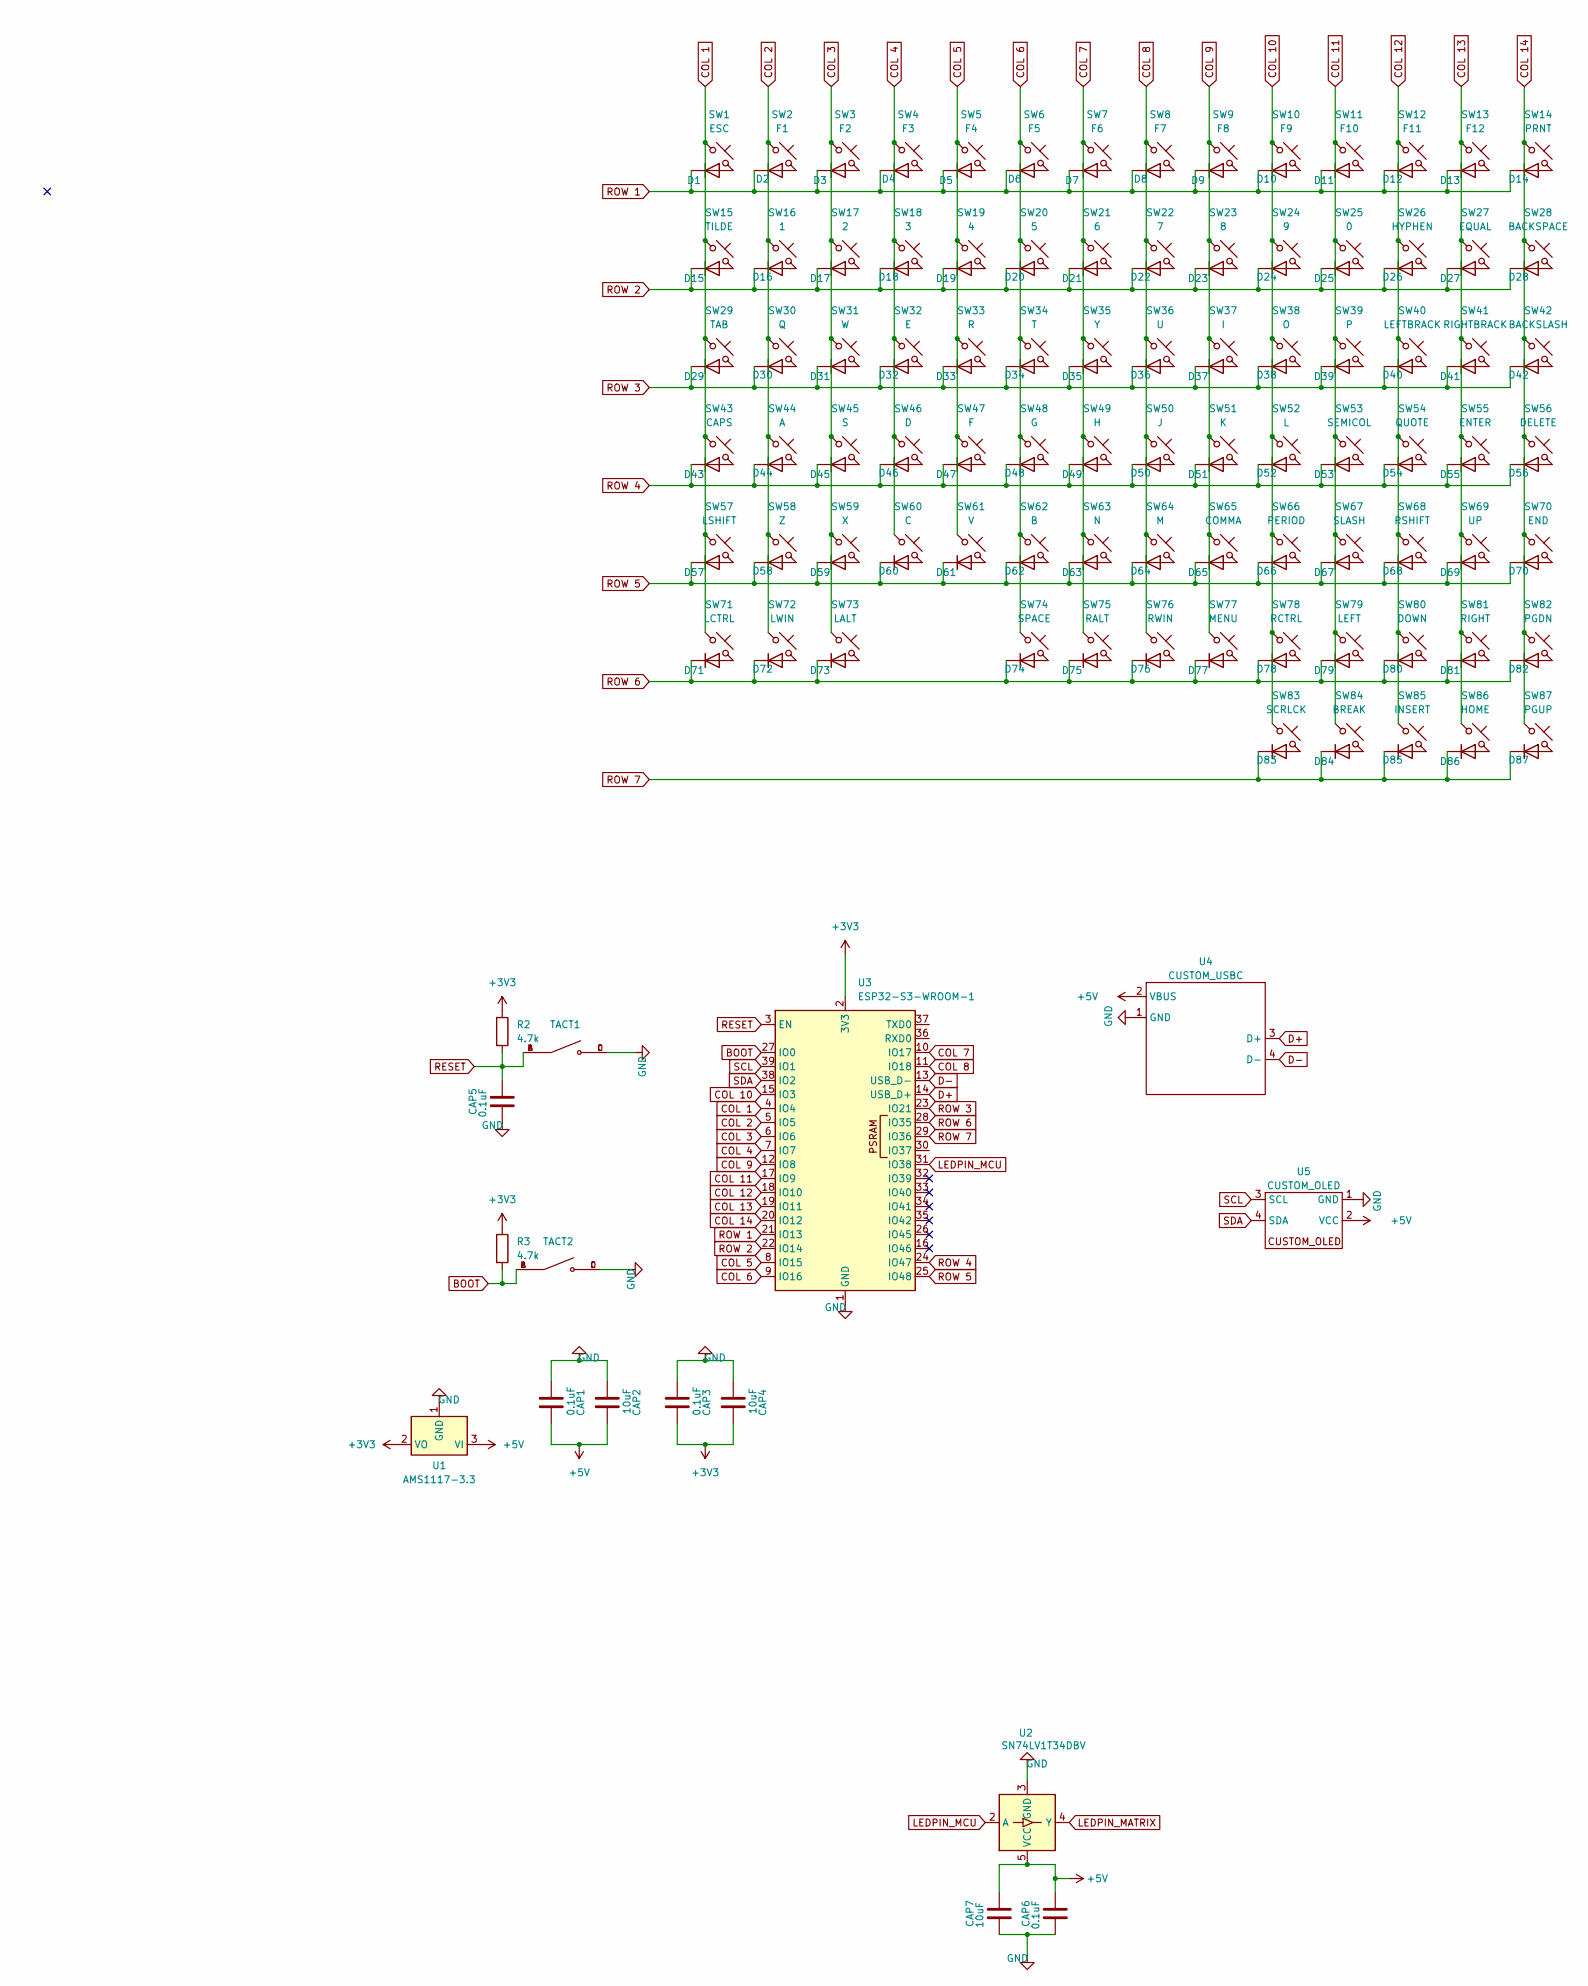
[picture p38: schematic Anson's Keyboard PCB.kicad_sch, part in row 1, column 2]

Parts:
C1, C2, C3, C4, C5, C6, C7, C8, C9, C10, C11, C12, C13, C14, C15, C16, C17, C18, C19, C20, C21, C22, C23, C24, C25, C26, C27, C28, C29, C30, C31, C32, C33, C34, C35, C36, C37, C38, C39, C40, C41, C42, C43, C44, C45, C46, C47, C48, C49, C50, C51, C52, C53, C54, C55, C56, C57, C58, C59, C60, C61, C62, C63, C64, C65, C66, C67, C68, C69, C70, C71, C72, C73, C74, C75, C76, C77, C78, C79, C80, C81, C82, C83, C84, C85, C86, C87, C88, C89, C90, C91: 0.1uF; C_1206_3216Metric_Pad1.33x1.80mm_HandSolder
CAP1, CAP3, CAP5, CAP6: 0.1uF; C_1206_3216Metric_Pad1.33x1.80mm_HandSolder
CAP2, CAP4, CAP7: 10uF; C_1206_3216Metric_Pad1.33x1.80mm_HandSolder
D1, D2, D3, D4, D5, D6, D7, D8, D9, D10, D11, D12, D13, D14, D15, D16, D17, D18, D19, D20, D21, D22, D23, D24, D25, D26, D27, D28, D29, D30, D31, D32, D33, D34, D35, D36, D37, D38, D39, D40, D41, D42, D43, D44, D45, D46, D47, D48, D49, D50, D51, D52, D53, D54, D55, D56, D57, D58, D59, D60, D61, D62, D63, D64, D65, D66, D67, D68, D69, D70, D71, D72, D73, D74, D75, D76, D77, D78, D79, D80, D81, D82, D83, D84, D85, D86, D87: D; D_SOD-123F
LED1, LED2, LED3, LED4, LED5, LED6, LED7, LED8, LED9, LED10, LED11, LED12, LED13, LED14, LED15, LED16, LED17, LED18, LED19, LED20, LED21, LED22, LED23, LED24, LED25, LED26, LED27, LED28, LED29, LED30, LED31, LED32, LED33, LED34, LED35, LED36, LED37, LED38, LED39, LED40, LED41, LED42, LED43, LED44, LED45, LED46, LED47, LED48, LED49, LED50, LED51, LED52, LED53, LED54, LED55, LED56, LED57, LED58, LED59, LED60, LED61, LED62, LED63, LED64, LED65, LED66, LED67, LED68, LED69, LED70, LED71, LED72, LED73, LED74, LED75, LED76, LED77, LED78, LED79, LED80, LED81, LED82, LED83, LED84, LED85, LED86, LED87, LED88, LED89, LED90, LED91: SK6812MINI; SK6812MINI-E
R2, R3: 4.7k; R_1206_3216Metric_Pad1.30x1.75mm_HandSolder
SW1: ESC; SW_Hotswap_Kailh_MX_Plated_1.00u
SW2: F1; SW_Hotswap_Kailh_MX_Plated_1.00u
SW3: F2; SW_Hotswap_Kailh_MX_Plated_1.00u
SW4: F3; SW_Hotswap_Kailh_MX_Plated_1.00u
SW5: F4; SW_Hotswap_Kailh_MX_Plated_1.00u
SW6: F5; SW_Hotswap_Kailh_MX_Plated_1.00u
SW7: F6; SW_Hotswap_Kailh_MX_Plated_1.00u
SW8: F7; SW_Hotswap_Kailh_MX_Plated_1.00u
SW9: F8; SW_Hotswap_Kailh_MX_Plated_1.00u
SW10: F9; SW_Hotswap_Kailh_MX_Plated_1.00u
SW11: F10; SW_Hotswap_Kailh_MX_Plated_1.00u
SW12: F11; SW_Hotswap_Kailh_MX_Plated_1.00u
SW13: F12; SW_Hotswap_Kailh_MX_Plated_1.00u
SW14: PRNT; SW_Hotswap_Kailh_MX_Plated_1.00u
SW15: TILDE; SW_Hotswap_Kailh_MX_Plated_1.00u
SW16: 1; SW_Hotswap_Kailh_MX_Plated_1.00u
SW17: 2; SW_Hotswap_Kailh_MX_Plated_1.00u
SW18: 3; SW_Hotswap_Kailh_MX_Plated_1.00u
SW19: 4; SW_Hotswap_Kailh_MX_Plated_1.00u
SW20: 5; SW_Hotswap_Kailh_MX_Plated_1.00u
SW21: 6; SW_Hotswap_Kailh_MX_Plated_1.00u
SW22: 7; SW_Hotswap_Kailh_MX_Plated_1.00u
SW23: 8; SW_Hotswap_Kailh_MX_Plated_1.00u
SW24: 9; SW_Hotswap_Kailh_MX_Plated_1.00u
SW25: 0; SW_Hotswap_Kailh_MX_Plated_1.00u
SW26: HYPHEN; SW_Hotswap_Kailh_MX_Plated_1.00u
SW27: EQUAL; SW_Hotswap_Kailh_MX_Plated_1.00u
SW28: BACKSPACE; SW_Hotswap_Kailh_MX_Plated_2.00u
SW29: TAB; SW_Hotswap_Kailh_MX_Plated_1.50u
SW30: Q; SW_Hotswap_Kailh_MX_Plated_1.00u
SW31: W; SW_Hotswap_Kailh_MX_Plated_1.00u
SW32: E; SW_Hotswap_Kailh_MX_Plated_1.00u
SW33: R; SW_Hotswap_Kailh_MX_Plated_1.00u
SW34: T; SW_Hotswap_Kailh_MX_Plated_1.00u
SW35: Y; SW_Hotswap_Kailh_MX_Plated_1.00u
SW36: U; SW_Hotswap_Kailh_MX_Plated_1.00u
SW37: I; SW_Hotswap_Kailh_MX_Plated_1.00u
SW38: O; SW_Hotswap_Kailh_MX_Plated_1.00u
SW39: P; SW_Hotswap_Kailh_MX_Plated_1.00u
SW40: LEFTBRACK; SW_Hotswap_Kailh_MX_Plated_1.00u
SW41: RIGHTBRACK; SW_Hotswap_Kailh_MX_Plated_1.00u
SW42: BACKSLASH; SW_Hotswap_Kailh_MX_Plated_1.50u
SW43: CAPS; SW_Hotswap_Kailh_MX_Plated_1.75u
SW44: A; SW_Hotswap_Kailh_MX_Plated_1.00u
SW45: S; SW_Hotswap_Kailh_MX_Plated_1.00u
SW46: D; SW_Hotswap_Kailh_MX_Plated_1.00u
SW47: F; SW_Hotswap_Kailh_MX_Plated_1.00u
SW48: G; SW_Hotswap_Kailh_MX_Plated_1.00u
SW49: H; SW_Hotswap_Kailh_MX_Plated_1.00u
SW50: J; SW_Hotswap_Kailh_MX_Plated_1.00u
SW51: K; SW_Hotswap_Kailh_MX_Plated_1.00u
SW52: L; SW_Hotswap_Kailh_MX_Plated_1.00u
SW53: SEMICOL; SW_Hotswap_Kailh_MX_Plated_1.00u
SW54: QUOTE; SW_Hotswap_Kailh_MX_Plated_1.00u
SW55: ENTER; SW_Hotswap_Kailh_MX_Plated_2.25u
SW56: DELETE; SW_Hotswap_Kailh_MX_Plated_1.00u
SW57: LSHIFT; SW_Hotswap_Kailh_MX_Plated_2.25u
SW58: Z; SW_Hotswap_Kailh_MX_Plated_1.00u
SW59: X; SW_Hotswap_Kailh_MX_Plated_1.00u
SW60: C; SW_Hotswap_Kailh_MX_Plated_1.00u
SW61: V; SW_Hotswap_Kailh_MX_Plated_1.00u
SW62: B; SW_Hotswap_Kailh_MX_Plated_1.00u
SW63: N; SW_Hotswap_Kailh_MX_Plated_1.00u
SW64: M; SW_Hotswap_Kailh_MX_Plated_1.00u
SW65: COMMA; SW_Hotswap_Kailh_MX_Plated_1.00u
SW66: PERIOD; SW_Hotswap_Kailh_MX_Plated_1.00u
SW67: SLASH; SW_Hotswap_Kailh_MX_Plated_1.00u
SW68: RSHIFT; SW_Hotswap_Kailh_MX_Plated_2.75u
SW69: UP; SW_Hotswap_Kailh_MX_Plated_1.00u
SW70: END; SW_Hotswap_Kailh_MX_Plated_1.00u
SW71: LCTRL; SW_Hotswap_Kailh_MX_Plated_1.25u
SW72: LWIN; SW_Hotswap_Kailh_MX_Plated_1.25u
SW73: LALT; SW_Hotswap_Kailh_MX_Plated_1.25u
SW74: SPACE; SW_Hotswap_Kailh_MX_Plated_6.25u
SW75: RALT; SW_Hotswap_Kailh_MX_Plated_1.25u
SW76: RWIN; SW_Hotswap_Kailh_MX_Plated_1.25u
SW77: MENU; SW_Hotswap_Kailh_MX_Plated_1.25u
SW78: RCTRL; SW_Hotswap_Kailh_MX_Plated_1.25u
SW79: LEFT; SW_Hotswap_Kailh_MX_Plated_1.00u
SW80: DOWN; SW_Hotswap_Kailh_MX_Plated_1.00u
SW81: RIGHT; SW_Hotswap_Kailh_MX_Plated_1.00u
SW82: PGDN; SW_Hotswap_Kailh_MX_Plated_1.00u
SW83: SCRLCK; SW_Hotswap_Kailh_MX_Plated_1.00u
SW84: BREAK; SW_Hotswap_Kailh_MX_Plated_1.00u
SW85: INSERT; SW_Hotswap_Kailh_MX_Plated_1.00u
SW86: HOME; SW_Hotswap_Kailh_MX_Plated_1.00u
SW87: PGUP; SW_Hotswap_Kailh_MX_Plated_1.00u
TACT1, TACT2: TS-1187A-B-A-B; SW_TS-1187A-B-A-B; PARTREV A0
U1: AMS1117-3.3; SOT-223-3_TabPin2
U2: SN74LV1T34DBV; SOT-23-5
U3: ESP32-S3-WROOM-1
U4: CUSTOM_USBC
U5: CUSTOM_OLED

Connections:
+3V3: CAP3.2, CAP4.2, R2.1, R3.1, U1.2 (VO), U3.2 (3V3)
+5V: C1.1, C2.1, C3.1, C4.1, C5.1, C6.1, C7.1, C8.1, C9.1, C10.1, C11.1, C12.1, C13.1, C14.1, C15.1, C16.1, C17.1, C18.1, C19.1, C20.1, C21.1, C22.1, C23.1, C24.1, C25.1, C26.1, C27.1, C28.1, C29.1, C30.1, C31.1, C32.1, C33.1, C34.1, C35.1, C36.1, C37.1, C38.1, C39.1, C40.1, C41.1, C42.1, C43.1, C44.1, C45.1, C46.1, C47.1, C48.1, C49.1, C50.1, C51.1, C52.1, C53.1, C54.1, C55.1, C56.1, C57.1, C58.1, C59.1, C60.1, C61.1, C62.1, C63.1, C64.1, C65.1, C66.1, C67.1, C68.1, C69.1, C70.1, C71.1, C72.1, C73.1, C74.1, C75.1, C76.1, C77.1, C78.1, C79.1, C80.1, C81.1, C82.1, C83.1, C84.1, C85.1, C86.1, C87.1, C88.1, C89.1, C90.1, C91.1, CAP1.2, CAP2.2, CAP6.2, CAP7.2, LED1.4 (VDD), LED2.4 (VDD), LED3.4 (VDD), LED4.4 (VDD), LED5.4 (VDD), LED6.4 (VDD), LED7.4 (VDD), LED8.4 (VDD), LED9.4 (VDD), LED10.4 (VDD), LED11.4 (VDD), LED12.4 (VDD), LED13.4 (VDD), LED14.4 (VDD), LED15.4 (VDD), LED16.4 (VDD), LED17.4 (VDD), LED18.4 (VDD), LED19.4 (VDD), LED20.4 (VDD), LED21.4 (VDD), LED22.4 (VDD), LED23.4 (VDD), LED24.4 (VDD), LED25.4 (VDD), LED26.4 (VDD), LED27.4 (VDD), LED28.4 (VDD), LED29.4 (VDD), LED30.4 (VDD), LED31.4 (VDD), LED32.4 (VDD), LED33.4 (VDD), LED34.4 (VDD), LED35.4 (VDD), LED36.4 (VDD), LED37.4 (VDD), LED38.4 (VDD), LED39.4 (VDD), LED40.4 (VDD), LED41.4 (VDD), LED42.4 (VDD), LED43.4 (VDD), LED44.4 (VDD), LED45.4 (VDD), LED46.4 (VDD), LED47.4 (VDD), LED48.4 (VDD), LED49.4 (VDD), LED50.4 (VDD), LED51.4 (VDD), LED52.4 (VDD), LED53.4 (VDD), LED54.4 (VDD), LED55.4 (VDD), LED56.4 (VDD), LED57.4 (VDD), LED58.4 (VDD), LED59.4 (VDD), LED60.4 (VDD), LED61.4 (VDD), LED62.4 (VDD), LED63.4 (VDD), LED64.4 (VDD), LED65.4 (VDD), LED66.4 (VDD), LED67.4 (VDD), LED68.4 (VDD), LED69.4 (VDD), LED70.4 (VDD), LED71.4 (VDD), LED72.4 (VDD), LED73.4 (VDD), LED74.4 (VDD), LED75.4 (VDD), LED76.4 (VDD), LED77.4 (VDD), LED78.4 (VDD), LED79.4 (VDD), LED80.4 (VDD), LED81.4 (VDD), LED82.4 (VDD), LED83.4 (VDD), LED84.4 (VDD), LED85.4 (VDD), LED86.4 (VDD), LED87.4 (VDD), LED88.4 (VDD), LED89.4 (VDD), LED90.4 (VDD), LED91.4 (VDD), U1.3 (VI), U2.5 (VCC), U4.2 (VBUS), U5.2 (VCC)
BOOT: R3.2, TACT2.A, TACT2.B, U3.27 (IO0)
COL 1: SW1.1, SW15.1, SW29.1, SW43.1, SW57.1, SW71.1, U3.4 (IO4)
COL 2: SW2.1, SW16.1, SW30.1, SW44.1, SW58.1, SW72.1, U3.5 (IO5)
COL 3: SW3.1, SW17.1, SW31.1, SW45.1, SW59.1, SW73.1, U3.6 (IO6)
COL 4: SW4.1, SW18.1, SW32.1, SW46.1, SW60.1, U3.7 (IO7)
COL 5: SW5.1, SW19.1, SW33.1, SW47.1, SW61.1, U3.8 (IO15)
COL 6: SW6.1, SW20.1, SW34.1, SW48.1, SW62.1, SW74.1, U3.9 (IO16)
COL 7: SW7.1, SW21.1, SW35.1, SW49.1, SW63.1, SW75.1, U3.10 (IO17)
COL 8: SW8.1, SW22.1, SW36.1, SW50.1, SW64.1, SW76.1, U3.11 (IO18)
COL 9: SW9.1, SW23.1, SW37.1, SW51.1, SW65.1, SW77.1, U3.12 (IO8)
COL 10: SW10.1, SW24.1, SW38.1, SW52.1, SW66.1, SW78.1, SW83.1, U3.15 (IO3)
COL 11: SW11.1, SW25.1, SW39.1, SW53.1, SW67.1, SW79.1, SW84.1, U3.17 (IO9)
COL 12: SW12.1, SW26.1, SW40.1, SW54.1, SW68.1, SW80.1, SW85.1, U3.18 (IO10)
COL 13: SW13.1, SW27.1, SW41.1, SW55.1, SW69.1, SW81.1, SW86.1, U3.19 (IO11)
COL 14: SW14.1, SW28.1, SW42.1, SW56.1, SW70.1, SW82.1, SW87.1, U3.20 (IO12)
D+: U3.14 (USB_D+), U4.3 (D+)
D-: U3.13 (USB_D-), U4.4 (D-)
GND: C1.2, C2.2, C3.2, C4.2, C5.2, C6.2, C7.2, C8.2, C9.2, C10.2, C11.2, C12.2, C13.2, C14.2, C15.2, C16.2, C17.2, C18.2, C19.2, C20.2, C21.2, C22.2, C23.2, C24.2, C25.2, C26.2, C27.2, C28.2, C29.2, C30.2, C31.2, C32.2, C33.2, C34.2, C35.2, C36.2, C37.2, C38.2, C39.2, C40.2, C41.2, C42.2, C43.2, C44.2, C45.2, C46.2, C47.2, C48.2, C49.2, C50.2, C51.2, C52.2, C53.2, C54.2, C55.2, C56.2, C57.2, C58.2, C59.2, C60.2, C61.2, C62.2, C63.2, C64.2, C65.2, C66.2, C67.2, C68.2, C69.2, C70.2, C71.2, C72.2, C73.2, C74.2, C75.2, C76.2, C77.2, C78.2, C79.2, C80.2, C81.2, C82.2, C83.2, C84.2, C85.2, C86.2, C87.2, C88.2, C89.2, C90.2, C91.2, CAP1.1, CAP2.1, CAP3.1, CAP4.1, CAP5.1, CAP6.1, CAP7.1, LED1.2 (VSS), LED2.2 (VSS), LED3.2 (VSS), LED4.2 (VSS), LED5.2 (VSS), LED6.2 (VSS), LED7.2 (VSS), LED8.2 (VSS), LED9.2 (VSS), LED10.2 (VSS), LED11.2 (VSS), LED12.2 (VSS), LED13.2 (VSS), LED14.2 (VSS), LED15.2 (VSS), LED16.2 (VSS), LED17.2 (VSS), LED18.2 (VSS), LED19.2 (VSS), LED20.2 (VSS), LED21.2 (VSS), LED22.2 (VSS), LED23.2 (VSS), LED24.2 (VSS), LED25.2 (VSS), LED26.2 (VSS), LED27.2 (VSS), LED28.2 (VSS), LED29.2 (VSS), LED30.2 (VSS), LED31.2 (VSS), LED32.2 (VSS), LED33.2 (VSS), LED34.2 (VSS), LED35.2 (VSS), LED36.2 (VSS), LED37.2 (VSS), LED38.2 (VSS), LED39.2 (VSS), LED40.2 (VSS), LED41.2 (VSS), LED42.2 (VSS), LED43.2 (VSS), LED44.2 (VSS), LED45.2 (VSS), LED46.2 (VSS), LED47.2 (VSS), LED48.2 (VSS), LED49.2 (VSS), LED50.2 (VSS), LED51.2 (VSS), LED52.2 (VSS), LED53.2 (VSS), LED54.2 (VSS), LED55.2 (VSS), LED56.2 (VSS), LED57.2 (VSS), LED58.2 (VSS), LED59.2 (VSS), LED60.2 (VSS), LED61.2 (VSS), LED62.2 (VSS), LED63.2 (VSS), LED64.2 (VSS), LED65.2 (VSS), LED66.2 (VSS), LED67.2 (VSS), LED68.2 (VSS), LED69.2 (VSS), LED70.2 (VSS), LED71.2 (VSS), LED72.2 (VSS), LED73.2 (VSS), LED74.2 (VSS), LED75.2 (VSS), LED76.2 (VSS), LED77.2 (VSS), LED78.2 (VSS), LED79.2 (VSS), LED80.2 (VSS), LED81.2 (VSS), LED82.2 (VSS), LED83.2 (VSS), LED84.2 (VSS), LED85.2 (VSS), LED86.2 (VSS), LED87.2 (VSS), LED88.2 (VSS), LED89.2 (VSS), LED90.2 (VSS), LED91.2 (VSS), TACT1.C, TACT1.D, TACT2.C, TACT2.D, U1.1 (GND), U2.3 (GND), U3.1 (GND), U3.40 (GND), U3.41 (GND), U4.1 (GND), U5.1 (GND)
LEDPIN_MATRIX: LED1.3 (DIN), U2.4 (Y)
LEDPIN_MCU: U2.2 (A), U3.31 (IO38)
unnamed: D1.2 (A), SW1.2
unnamed: D2.2 (A), SW2.2
unnamed: D3.2 (A), SW3.2
unnamed: D4.2 (A), SW4.2
unnamed: D5.2 (A), SW5.2
unnamed: D6.2 (A), SW6.2
unnamed: D7.2 (A), SW7.2
unnamed: D8.2 (A), SW8.2
unnamed: D9.2 (A), SW9.2
unnamed: D10.2 (A), SW10.2
unnamed: D11.2 (A), SW11.2
unnamed: D12.2 (A), SW12.2
unnamed: D13.2 (A), SW13.2
unnamed: D14.2 (A), SW14.2
unnamed: D15.2 (A), SW15.2
unnamed: D16.2 (A), SW16.2
unnamed: D17.2 (A), SW17.2
unnamed: D18.2 (A), SW18.2
unnamed: D19.2 (A), SW19.2
unnamed: D20.2 (A), SW20.2
unnamed: D21.2 (A), SW21.2
unnamed: D22.2 (A), SW22.2
unnamed: D23.2 (A), SW23.2
unnamed: D24.2 (A), SW24.2
unnamed: D25.2 (A), SW25.2
unnamed: D26.2 (A), SW26.2
unnamed: D27.2 (A), SW27.2
unnamed: D28.2 (A), SW28.2
unnamed: D29.2 (A), SW29.2
unnamed: D30.2 (A), SW30.2
unnamed: D31.2 (A), SW31.2
unnamed: D32.2 (A), SW32.2
unnamed: D33.2 (A), SW33.2
unnamed: D34.2 (A), SW34.2
unnamed: D35.2 (A), SW35.2
unnamed: D36.2 (A), SW36.2
unnamed: D37.2 (A), SW37.2
unnamed: D38.2 (A), SW38.2
unnamed: D39.2 (A), SW39.2
unnamed: D40.2 (A), SW40.2
unnamed: D41.2 (A), SW41.2
unnamed: D42.2 (A), SW42.2
unnamed: D43.2 (A), SW43.2
unnamed: D44.2 (A), SW44.2
unnamed: D45.2 (A), SW45.2
unnamed: D46.2 (A), SW46.2
unnamed: D47.2 (A), SW47.2
unnamed: D48.2 (A), SW48.2
unnamed: D49.2 (A), SW49.2
unnamed: D50.2 (A), SW50.2
unnamed: D51.2 (A), SW51.2
unnamed: D52.2 (A), SW52.2
unnamed: D53.2 (A), SW53.2
unnamed: D54.2 (A), SW54.2
unnamed: D55.2 (A), SW55.2
unnamed: D56.2 (A), SW56.2
unnamed: D57.2 (A), SW57.2
unnamed: D58.2 (A), SW58.2
unnamed: D59.2 (A), SW59.2
unnamed: D60.2 (A), SW60.2
unnamed: D61.2 (A), SW61.2
unnamed: D62.2 (A), SW62.2
unnamed: D63.2 (A), SW63.2
unnamed: D64.2 (A), SW64.2
unnamed: D65.2 (A), SW65.2
unnamed: D66.2 (A), SW66.2
unnamed: D67.2 (A), SW67.2
unnamed: D68.2 (A), SW68.2
unnamed: D69.2 (A), SW69.2
unnamed: D70.2 (A), SW70.2
unnamed: D71.2 (A), SW71.2
unnamed: D72.2 (A), SW72.2
unnamed: D73.2 (A), SW73.2
unnamed: D74.2 (A), SW74.2
unnamed: D75.2 (A), SW75.2
unnamed: D76.2 (A), SW76.2
unnamed: D77.2 (A), SW77.2
unnamed: D78.2 (A), SW78.2
unnamed: D79.2 (A), SW79.2
unnamed: D80.2 (A), SW80.2
unnamed: D81.2 (A), SW81.2
unnamed: D82.2 (A), SW82.2
unnamed: D83.2 (A), SW83.2
unnamed: D84.2 (A), SW84.2
unnamed: D85.2 (A), SW85.2
unnamed: D86.2 (A), SW86.2
unnamed: D87.2 (A), SW87.2
unnamed: LED1.1 (DOUT), LED2.3 (DIN)
unnamed: LED2.1 (DOUT), LED3.3 (DIN)
unnamed: LED3.1 (DOUT), LED4.3 (DIN)
unnamed: LED4.1 (DOUT), LED5.3 (DIN)
unnamed: LED5.1 (DOUT), LED6.3 (DIN)
unnamed: LED6.1 (DOUT), LED7.3 (DIN)
unnamed: LED7.1 (DOUT), LED8.3 (DIN)
unnamed: LED8.1 (DOUT), LED9.3 (DIN)
unnamed: LED9.1 (DOUT), LED10.3 (DIN)
unnamed: LED10.1 (DOUT), LED11.3 (DIN)
unnamed: LED11.1 (DOUT), LED12.3 (DIN)
unnamed: LED12.1 (DOUT), LED13.3 (DIN)
unnamed: LED13.1 (DOUT), LED14.3 (DIN)
unnamed: LED14.1 (DOUT), LED15.3 (DIN)
unnamed: LED15.1 (DOUT), LED16.3 (DIN)
unnamed: LED16.1 (DOUT), LED17.3 (DIN)
unnamed: LED17.1 (DOUT), LED18.3 (DIN)
unnamed: LED18.1 (DOUT), LED19.3 (DIN)
unnamed: LED19.1 (DOUT), LED20.3 (DIN)
unnamed: LED20.1 (DOUT), LED21.3 (DIN)
unnamed: LED21.1 (DOUT), LED22.3 (DIN)
unnamed: LED22.1 (DOUT), LED23.3 (DIN)
unnamed: LED23.1 (DOUT), LED24.3 (DIN)
unnamed: LED24.1 (DOUT), LED25.3 (DIN)
unnamed: LED25.1 (DOUT), LED26.3 (DIN)
unnamed: LED26.1 (DOUT), LED27.3 (DIN)
unnamed: LED27.1 (DOUT), LED28.3 (DIN)
unnamed: LED28.1 (DOUT), LED29.3 (DIN)
unnamed: LED29.1 (DOUT), LED30.3 (DIN)
unnamed: LED30.1 (DOUT), LED31.3 (DIN)
unnamed: LED31.1 (DOUT), LED32.3 (DIN)
unnamed: LED32.1 (DOUT), LED33.3 (DIN)
unnamed: LED33.1 (DOUT), LED34.3 (DIN)
unnamed: LED34.1 (DOUT), LED35.3 (DIN)
unnamed: LED35.1 (DOUT), LED36.3 (DIN)
unnamed: LED36.1 (DOUT), LED37.3 (DIN)
unnamed: LED37.1 (DOUT), LED38.3 (DIN)
unnamed: LED38.1 (DOUT), LED39.3 (DIN)
unnamed: LED39.1 (DOUT), LED40.3 (DIN)
unnamed: LED40.1 (DOUT), LED41.3 (DIN)
unnamed: LED41.1 (DOUT), LED42.3 (DIN)
unnamed: LED42.1 (DOUT), LED43.3 (DIN)
unnamed: LED43.1 (DOUT), LED44.3 (DIN)
unnamed: LED44.1 (DOUT), LED45.3 (DIN)
unnamed: LED45.1 (DOUT), LED46.3 (DIN)
unnamed: LED46.1 (DOUT), LED47.3 (DIN)
unnamed: LED47.1 (DOUT), LED48.3 (DIN)
unnamed: LED48.1 (DOUT), LED49.3 (DIN)
unnamed: LED49.1 (DOUT), LED50.3 (DIN)
unnamed: LED50.1 (DOUT), LED51.3 (DIN)
unnamed: LED51.1 (DOUT), LED52.3 (DIN)
unnamed: LED52.1 (DOUT), LED53.3 (DIN)
unnamed: LED53.1 (DOUT), LED54.3 (DIN)
unnamed: LED54.1 (DOUT), LED55.3 (DIN)
unnamed: LED55.1 (DOUT), LED56.3 (DIN)
unnamed: LED56.1 (DOUT), LED57.3 (DIN)
unnamed: LED57.1 (DOUT), LED58.3 (DIN)
unnamed: LED58.1 (DOUT), LED59.3 (DIN)
unnamed: LED59.1 (DOUT), LED60.3 (DIN)
unnamed: LED60.1 (DOUT), LED61.3 (DIN)
unnamed: LED61.1 (DOUT), LED62.3 (DIN)
unnamed: LED62.1 (DOUT), LED63.3 (DIN)
unnamed: LED63.1 (DOUT), LED64.3 (DIN)
unnamed: LED64.1 (DOUT), LED65.3 (DIN)
unnamed: LED65.1 (DOUT), LED66.3 (DIN)
unnamed: LED66.1 (DOUT), LED67.3 (DIN)
unnamed: LED67.1 (DOUT), LED68.3 (DIN)
unnamed: LED68.1 (DOUT), LED69.3 (DIN)
unnamed: LED69.1 (DOUT), LED70.3 (DIN)
unnamed: LED70.1 (DOUT), LED71.3 (DIN)
unnamed: LED71.1 (DOUT), LED72.3 (DIN)
unnamed: LED72.1 (DOUT), LED73.3 (DIN)
unnamed: LED73.1 (DOUT), LED74.3 (DIN)
unnamed: LED74.1 (DOUT), LED75.3 (DIN)
unnamed: LED75.1 (DOUT), LED76.3 (DIN)
unnamed: LED76.1 (DOUT), LED77.3 (DIN)
unnamed: LED77.1 (DOUT), LED78.3 (DIN)
unnamed: LED78.1 (DOUT), LED79.3 (DIN)
unnamed: LED79.1 (DOUT), LED80.3 (DIN)
unnamed: LED80.1 (DOUT), LED81.3 (DIN)
unnamed: LED81.1 (DOUT), LED82.3 (DIN)
unnamed: LED82.1 (DOUT), LED83.3 (DIN)
unnamed: LED83.1 (DOUT), LED84.3 (DIN)
unnamed: LED84.1 (DOUT), LED85.3 (DIN)
unnamed: LED85.1 (DOUT), LED86.3 (DIN)
unnamed: LED86.1 (DOUT), LED87.3 (DIN)
unnamed: LED87.1 (DOUT), LED88.3 (DIN)
unnamed: LED88.1 (DOUT), LED89.3 (DIN)
unnamed: LED89.1 (DOUT), LED90.3 (DIN)
unnamed: LED90.1 (DOUT), LED91.3 (DIN)
RESET: CAP5.2, R2.2, TACT1.A, TACT1.B, U3.3 (EN)
ROW 1: D1.1 (K), D2.1 (K), D3.1 (K), D4.1 (K), D5.1 (K), D6.1 (K), D7.1 (K), D8.1 (K), D9.1 (K), D10.1 (K), D11.1 (K), D12.1 (K), D13.1 (K), D14.1 (K), U3.21 (IO13)
ROW 2: D15.1 (K), D16.1 (K), D17.1 (K), D18.1 (K), D19.1 (K), D20.1 (K), D21.1 (K), D22.1 (K), D23.1 (K), D24.1 (K), D25.1 (K), D26.1 (K), D27.1 (K), D28.1 (K), U3.22 (IO14)
ROW 3: D29.1 (K), D30.1 (K), D31.1 (K), D32.1 (K), D33.1 (K), D34.1 (K), D35.1 (K), D36.1 (K), D37.1 (K), D38.1 (K), D39.1 (K), D40.1 (K), D41.1 (K), D42.1 (K), U3.23 (IO21)
ROW 4: D43.1 (K), D44.1 (K), D45.1 (K), D46.1 (K), D47.1 (K), D48.1 (K), D49.1 (K), D50.1 (K), D51.1 (K), D52.1 (K), D53.1 (K), D54.1 (K), D55.1 (K), D56.1 (K), U3.24 (IO47)
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

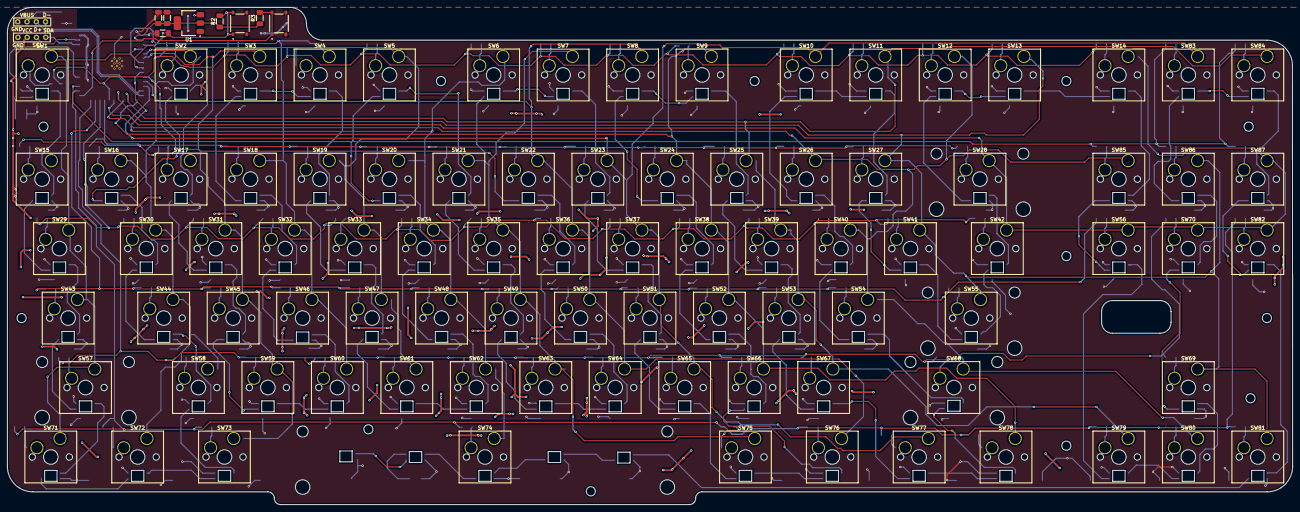
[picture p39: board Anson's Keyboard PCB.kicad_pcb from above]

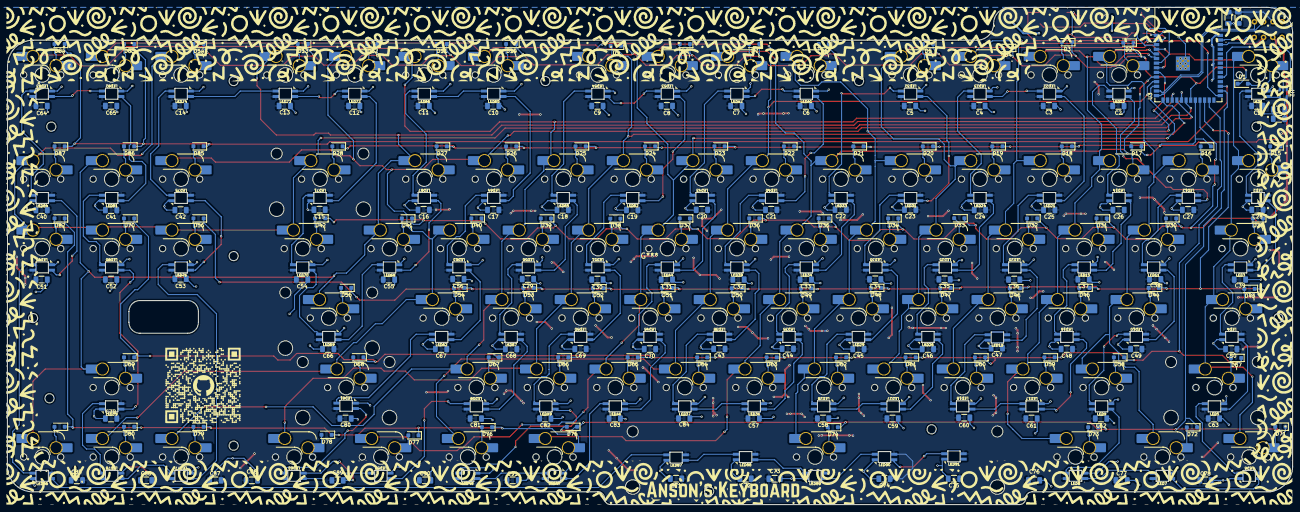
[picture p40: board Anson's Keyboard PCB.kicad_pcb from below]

Board: 2 copper layers, 352.5 x 136.4 mm, 372 parts (275 on the bottom side), 209 nets.

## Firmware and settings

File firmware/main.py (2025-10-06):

import board
import digitalio
import displayio
import adafruit_displayio_ssd1306
import supervisor
import time
import neopixel
import busio
from kmk.kmk_keyboard import KMKKeyboard
from kmk.keys import KC
from kmk.scanners import DiodeOrientation
from kmk.modules.layers import Layers
from kmk.modules.modtap import ModTap
from kmk.handlers.sequences import simple_key_sequence
from kmk.extensions.media_keys import MediaKeys
from kmk.extensions.RGB import RGB, AnimationModes
from kmk.extensions.international import International
from kmk.extensions.lock_status import LockStatus
from kmk.modules.split import Split
from kmk.extensions.led import LED
from kmk.extensions.oled import Oled, OledDisplayMode, OledReactionType
from kmk.modules.oneshot import OneShot
from kmk.modules.bluetooth import Bluetooth

keyboard = KMKKeyboard()

keyboard.row_pins = (board.IO13, board.IO14, board.IO21, board.IO47, board.IO48, board.IO35, board.IO36)

keyboard.col_pins = (board.IO4, board.IO5, board.IO6, board.IO7, board.IO15, board.IO16, board.IO17, 
                     board.IO18, board.IO8, board.IO3, board.IO9, board.IO10, board.IO11, board.IO12)

keyboard.diode_orientation = DiodeOrientation.COL2ROW

layers = Layers()
modtap = ModTap()
oneshot = OneShot()
bluetooth = Bluetooth()

media_keys = MediaKeys()
international = International()
lock_status = LockStatus()

NUM_LEDS = 91
led_pin = board.IO19  
pixels = neopixel.NeoPixel(led_pin, NUM_LEDS, brightness=0.5, auto_write=False)

i2c = busio.I2C(board.IO1, board.IO2)
display_bus = displayio.I2CDisplay(i2c, device_address=0x3C)
display = adafruit_displayio_ssd1306.SSD1306(display_bus, width=128, height=32)

wpm = 0
last_key_time = time.monotonic()
key_press_count = 0
led_mode = 0 
led_brightness = 0.5
custom_mode_active = False
custom_color = [255, 0, 0]  
custom_color_index = 0
custom_color_input = ""

def calculate_wpm():
    global wpm, last_key_time, key_press_count
    current_time = time.monotonic()
    time_diff = current_time - last_key_time
    
    if time_diff > 1.0:
        wpm = int((key_press_count / 5) * (60 / time_diff))
        key_press_count = 0
        last_key_time = current_time
    
    return wpm

def update_oled():
    global wpm, custom_mode_active, custom_color_index, custom_color_input
    
    display.fill(0)
    display.text("KMK Keyboard", 0, 0, 1)
    
    if custom_mode_active:
        if custom_color_index == 0:
            display.text(f"R:{custom_color_input}", 0, 16, 1)
        elif custom_color_index == 1:
            display.text(f"G:{custom_color_input}", 0, 16, 1)
        elif custom_color_index == 2:
            display.text(f"B:{custom_color_input}", 0, 16, 1)
    else:
        if bluetooth.active:
            display.text("BT Mode", 0, 8, 1)
        else:
            display.text("USB Mode", 0, 8, 1)
        
        display.text(f"WPM: {calculate_wpm()}", 0, 16, 1)
        
        if led_mode == 0:
            led_mode_text = "LED: Off"
        elif led_mode == 1:
            led_mode_text = "LED: RGB"
        else:
            led_mode_text = "LED: Custom"
        
        display.text(led_mode_text, 0, 24, 1)
    
    display.show()

def update_leds():
    global led_mode, led_brightness, custom_color

    if led_mode == 0:
        pixels.fill((0, 0, 0))
    elif led_mode == 1:
        for i in range(NUM_LEDS):
            pixel_index = (i * 256 // NUM_LEDS)
            pixels[i] = wheel(pixel_index & 255)
    elif led_mode == 2:
        r, g, b = custom_color
        pixels.fill((r, g, b))
    
    pixels.brightness = led_brightness
    pixels.show()

def wheel(pos):
    if pos < 0 or pos > 255:
        r = g = b = 0
    elif pos < 85:
        r = int(pos * 3)
        g = int(255 - pos * 3)
        b = 0
    elif pos < 170:
        pos -= 85
        r = int(255 - pos * 3)
        g = 0
        b = int(pos * 3)
    else:
        pos -= 170
        r = 0
        g = int(pos * 3)
        b = int(255 - pos * 3)
    return (r, g, b)

def on_pre_process(keyboard):
    global key_press_count, custom_mode_active, custom_color_input, custom_color_index, custom_color
    
    if custom_mode_active:
        for key in keyboard.active_keys:
            if key.code >= 30 and key.code <= 39:
                custom_color_input += str(key.code - 30)
                update_oled()
            elif key.code == 42:  
                if custom_color_input:
                    custom_color_input = custom_color_input[:-1]
                    update_oled()
            elif key.code == 40:
                if custom_color_input:
                    value = min(255, max(0, int(custom_color_input)))
                    custom_color[custom_color_index] = value
                    custom_color_index = (custom_color_index + 1) % 3
                    custom_color_input = ""
                    
                    if custom_color_index == 0: 
                        custom_mode_active = False
                        update_leds()
                    
                    update_oled()
        
        keyboard.active_keys = []
        return
    
    if keyboard.active_keys:
        key_press_count += len(keyboard.active_keys)
        update_oled()

def on_pre_process_key(keyboard, key, is_pressed):
    global led_mode, led_brightness, custom_mode_active
    
    ctrl_pressed = KC.LCTRL in keyboard.active_keys or KC.RCTRL in keyboard.active_keys
    alt_pressed = KC.LALT in keyboard.active_keys or KC.RALT in keyboard.active_keys
    shift_pressed = KC.LSHIFT in keyboard.active_keys or KC.RSHIFT in keyboard.active_keys
    
    if ctrl_pressed and alt_pressed and key == KC.PAUS and is_pressed:
        led_mode = (led_mode + 1) % 3
        update_leds()
        update_oled()
        return False
    
    if ctrl_pressed and alt_pressed and key == KC.PGUP and is_pressed:
        custom_mode_active = True
        custom_color_index = 0
        custom_color_input = ""
        update_oled()
        return False
    
    if ctrl_pressed and alt_pressed and shift_pressed and key == KC.UP and is_pressed:
        led_brightness = min(1.0, led_brightness + 0.05)
        update_leds()
        update_oled()
        return False
    
    if ctrl_pressed and alt_pressed and shift_pressed and key == KC.DOWN and is_pressed:
        led_brightness = max(0.0, led_brightness - 0.05)
        update_leds()
        update_oled()
        return False
    
    return True

pause_break_pin = digitalio.DigitalInOut(board.IO36)
pause_break_pin.direction = digitalio.Direction.INPUT
pause_break_pin.pull = digitalio.Pull.UP

if not pause_break_pin.value:
    bluetooth.active = True

keyboard.before_matrix_scan(on_pre_process)
keyboard.before_hid_send(on_pre_process_key)

keyboard.keymap = [
    [
        # Row 1
        KC.ESC,  KC.F1,   KC.F2,  KC.F3,  KC.F4,  KC.F5,  KC.F6,  KC.F7,  KC.F8,  KC.F9,   KC.F10,  KC.F11,  KC.F12,  KC.PSCR,
        # Row 2
        KC.GRV,  KC.N1,   KC.N2,  KC.N3,  KC.N4,  KC.N5,  KC.N6,  KC.N7,  KC.N8,  KC.N9,   KC.N0,   KC.MINS, KC.EQL,  KC.BSPC,
        # Row 3
        KC.TAB,  KC.Q,    KC.W,   KC.E,   KC.R,   KC.T,   KC.Y,   KC.U,   KC.I,   KC.O,    KC.P,    KC.LBRC, KC.RBRC, KC.BSLS,
        # Row 4
        KC.CAPS, KC.A,    KC.S,   KC.D,   KC.F,   KC.G,   KC.H,   KC.J,   KC.L,   KC.SCLN, KC.QUOT, KC.ENT,  KC.DEL,  KC.NO,
        # Row 5
        KC.LSFT, KC.Z,    KC.X,   KC.C,   KC.V,   KC.B,   KC.N,   KC.M,   KC.COMM, KC.DOT,  KC.SLSH, KC.RSFT, KC.UP,   KC.END,
        # Row 6
        KC.LCTL, KC.LGUI, KC.LALT, KC.NO, KC.NO, KC.SPC, KC.RALT, KC.RGUI, KC.APP, KC.RCTL, KC.LEFT, KC.DOWN, KC.RGHT, KC.PGDN,
        # Row 7
        KC.NO,   KC.NO,   KC.NO,  KC.NO,  KC.NO,  KC.NO,  KC.NO,  KC.NO,  KC.NO,   KC.SLCK, KC.PAUS, KC.INS,  KC.HOME, KC.PGUP,
    ],
]

keyboard.modules = [layers, modtap, oneshot, bluetooth]

keyboard.extensions = [media_keys, international, lock_status]

def main():
    update_oled()
    
    last_oled_update = time.monotonic()
    last_led_update = time.monotonic()
    
    keyboard.go()
    
    while True:
        current_time = time.monotonic()
        
        if current_time - last_oled_update >= 0.1:
            update_oled()
            last_oled_update = current_time
        
        if current_time - last_led_update >= 0.05:
            update_leds()
            last_led_update = current_time
        
        time.sleep(0.001) 

if __name__ == "__main__":
    main()

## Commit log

2025-10-07 Add bom
    multiple fixes
    [bom.csv]
2025-10-10 Update bom
    [bom.csv]
2025-10-19 Updated PCB to use hotswap
    Rewired everything to use hotswap sockets instead of direct switch soldering
    [Anson's Keyboard PCB.kicad_pcb, Anson's Keyboard PCB.kicad_sch, kailhSocket.STEP]
2025-10-20 Updated for better manufacturability
    Rerouted some parts
    [Anson's Keyboard PCB.kicad_pcb]
2025-10-20 Multiple Changes
    Added more PCB mounting holes
    Changed PCB mounting hole size to M2
    Added updated PCB Gerber
    Added updated PCB 3D model
    Updated assembled .f3z [AWS outage broke Autodesk, currently can't export f3z] and .STEP for new mounting points and changes
    Updated BOM for additional screws and heatset inserts
    CaseStand.step now uses screws, which is more reliable than slide-and-click mount
    Removed branding on printed parts
    Split large parts for printability
    Updated README with new assets
    [Anson's Keyboard PCB.kicad_pcb, Anson's Keyboard PCB.step, Assembled Keyboard.step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]
